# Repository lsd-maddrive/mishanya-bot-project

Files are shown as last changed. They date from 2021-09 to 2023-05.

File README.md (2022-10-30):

# mishanya-bot-project

Проект по разработке/оживлению человекоподного робота Мишаня -> [Описание робота](docs/equipment/equipment.md)

- [Подготовка окружения](#подготовка-окружения)
  - [Установка форматера глобально](#установка-форматера-глобально)
  - [Установка инструментов линта через локальное окружение (poetry)](#установка-инструментов-линта-через-локальное-окружение-poetry)
- [Пара моментов по разработке](#пара-моментов-по-разработке)
- [Заметки по работе в-целом](#заметки-по-работе-в-целом)
- [Глобальные цели](#глобальные-цели)
- [Ресурсы](#ресурсы)

## Подготовка окружения

Проект настроен на проверку кода по линтеру через GitHub actions. В результате проверки можно увидеть на [этой странице](https://github.com/lsd-maddrive/mishanya-bot-project/actions/workflows/lint.yml) в ветках. Можно брать проверки оттуда, а можно установить инструменты себе локально и проверять при каждой коммите (инструмент pre-commit) линтерами.

Для локальной работы линтеров нужно установить инструменты:

- pre-commit (python пакет)
- cpplint (python пакет)
- clang-format (бинарная утилита)

### Установка форматера глобально

Устанавливаем `clang-format`

- Windows

  Используйте установочный файл с [официального сайта LLVM](https://llvm.org/builds/) 

- Linux

  ```bash
  sudo apt install clang-format
  ```

### Установка инструментов линта через локальное окружение (poetry)

**Poetry** - это удобный инструмент для организации виртуального окружения.

1. Устанавливаем make
    - Windows:
  
      Устанавливаем [chocolatey](https://chocolatey.org/install) и устанавливаем `make` с помощью команды:

      ```bash
      choco install make 
      ```

    - Linux:

      ```bash
      sudo apt-get install build-essential
      ```

1. Устанавливаем `python 3.8`

   - Windows

      Устанавливаем через [официальный установщик](https://www.python.org/downloads/)

   - Linux

      ```bash
      sudo apt install python3.8-dev
      ```

1. Устанавливаем [poetry](https://python-poetry.org/docs/#installing-with-the-official-installer)

    - Windows

      Используйте [официальные инструкции](https://python-poetry.org/docs/#installing-with-the-official-installer) или команду `powershell`

      ```bash
      (Invoke-WebRequest -Uri https://install.python-poetry.org -UseBasicParsing).Content | py -
      ```

    - Linux

      ```bash
      make poetry-install
      ```

1. Устанавливаем требуемые пакеты и инструменты с помощью команды

    ```bash
    make env-init
    ```

## Пара моментов по разработке

- Основная разработка ведется через ветку `develop`
- Flow работы над задачей
  - Для нее обязательно должна быть создана задача в issues, например `#8 Разработка кода для модуля локтя руки`
  - Во вкладке Projects переводите ее в `In progress` колонку
  - Создаете ветку с названием `8_hand_module_code_creation`
  - Работаете в этой ветке (комитить желательно делать по завершении какой-то части задачи и всегда в конце дня)
  - После завершения работы создаете Pull Request, в котором описываете, что сделано и назначаете ревьюверов (всех остальных в проекте)
  - Как только ревью пройдено и получено подтверждение - ветку сливает администратор (Леша)
- Канбан доска для проекта - вкладка Projects
- Файлы больше 100 KB храним в [Git LFS](https://git-lfs.github.com/)
- Для каждой разработанной подсистемы требуется написать маленький тест, который будет запускать простую программу, использующую разработанные функции и демонстрировать работоспособность

## Заметки по работе в-целом

- Не стесняемся задавать вопросы по *любой* теме насчет проекта - лучше, чтобы все понимали, в каком состоянии что сейчас находится, чем что-то скрывать
- Чат не для хранения - его может заваливать переписками и общением!
- Документы, полезные ссылки или другая полезная инфа - обязательно в `.md` файлы в репозитории хранить!
- Если файлом надо поделиться - кладем в репо и отсюда кидаем ссылку в чат (так гарантируется, что ничего не потеряется) 

## Глобальные цели

- Stage 1 - Восстановление базового функционала
  - Стараемся добиться того, чтобы все части робота работали и все могло управляться через единый МК
- Stage 2 - Добавляется интеграция с ROS и организуется математическая модель кинематики с имплементацией в роботе
- Stage 3 - Разработка SDK для робота (прослойка для верхнеуровневого управления)
- Stage 4 - Разработка сценариев для автономного движения и выполнения задач (демо продукта, сбор информации с людей, и т.д.)

## Ресурсы

- [Хранилище больших файлов](https://disk.yandex.ru/d/VdiUvhrjdGQnWQ) (за доступом обращайтесь к [@KaiL4eK](https://github.com/KaiL4eK))

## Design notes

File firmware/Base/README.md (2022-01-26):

### TARGET

The template runs on an STM32 Nucleo64-F767ZI board.

### Useful links
* [Reference manual (RM)](https://www.st.com/content/ccc/resource/technical/document/reference_manual/group0/96/8b/0d/ec/16/22/43/71/DM00224583/files/DM00224583.pdf/jcr:content/translations/e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)
* [Datasheet (DS)](https://www.st.com/content/ccc/resource/technical/document/datasheet/group3/c5/37/9c/1d/a6/09/4e/1a/DM00273119/files/DM00273119.pdf/jcr:content/translations/en.DM002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)
* [Nucleo pinout](https://os.mbed.com/platforms/ST-Nucleo-F767zi/)

### Notes

Based on demos from https://github.com/ChibiOS/ChibiOS

### Information for developers

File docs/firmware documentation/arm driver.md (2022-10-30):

# arm driver v1.0 

Данный файл содержить информацию по использованию модуля `arm_driver`.
На данный момент с помощью данного модуля полностью описана работа:
- локтевого сустава робота `elbow_driver`;

## Описание конструкий

В h-файле находятся компоненты, которые описывают часть руки робота:

1. arm_side_t

enum для выбора левой или правой руки.

2. driver_t

enum для выбора типа драйвера:
- BB - управление осуществляется четырьмя выводами (4 ШИМ);
- RED - управление осуществляется тремя выводами (1 ШИМ, 2 дискретных).

3. pwm_channel_t

Структура с информацией о ШИМ-каналах

- uint8_t ch_pwm_1 - первый используемый канал ШИМ; 
- uint8_t ch_pwm_2 - второй используемый канал ШИМ;
- uint8_t alt_func_1 - номер альтернативной функции первого канала ШИМ;
- uint8_t alt_func_2 - номер альтернативной функции второго канала ШИМ.

4. pwm_ctx_t

Структура с информацией о настройках ШИМ.

- PWMDriver driver_ptr -  указатель на используемый таймер;
- PWMConfig pwm_conf -  структура с настройкой ШИМа;
- pwm_channel_t pwm_ch - описана в 4 пункте.

5. line_driver_t

Структура с информацией о используемых выводах.

- ioline_t     lin_1:
  * Нижний ключ первого полумоста при работе с BB;
  * Первый цифровой вывод при работе с RED.
- ioline_t     lin_2:
  * Нижний ключ второго полумоста при работе с BB;
  * Второй цифровой вывод при работе с RED.
- ioline_t     hin_1:
  * Верхний ключ первого полумоста при работе с BB;
  * Вывод ШИМ при работе с RED.
- ioline_t     hin_2:
  * Верхний ключ второго полумоста при работе с BB;
  * Не используется при работе с RED.

6. normalize_angle_t

- target - флаг был ли достигнут заданный угол
- target_angle - заданный угол;
- max_norm_angle - нормированное значение энкодера соответствущее максимальному углу;  
- min_norm_angle - нормированное значение энкодера соответствущее минимальному углу;
- shift - смещение между нулем и минимальным ненормированным углом;
- zero_cross - флаг есть ли нуль между крайними положениями энкодера.

7. angle_lim_t

- min_angle - минимальное положение энкодера 
- max_angle - максимальное положение энкодера

8. traking_cs_t

- normalize_angle - структура из пунтка 6;
- angle_lim - структура из пункта 7;
- arm_PID - настройка регулятора;
- angle_dead_zone - мертвая зона регулирования

9. control_driver_t

Объединяет в себе структуры из пункта 4 и 5.

10. arm_system_t

Объединяет в себе структуры из пункта 8 и 9.

11. arm_driver_ctx_t

Содержит enum из пункта 2, указатели на функции управления рукой
и массив из двух элементов типа control_driver_t (первый элемент описывает левую руку, второй правую). 

## Описание функций

Модуль содержит 4 функции:

1. Инициализация драйвера 
```c
void driver_init(const arm_driver_ctx_t *arm_driver);
```
Принимает полностью описанную часть руки робота.

2. Поднятие части руки робота вверх
```c
void arm_up(arm_side_t side, const arm_driver_ctx_t *arm_driver, uint16_t period);
```
Принимает выбор правой или левой руки, полностью описанную часть руки робота и необходимый период ШИМ.

3. Опускание части руки робота вверх
```c
void arm_down(arm_side_t side, const arm_driver_ctx_t *arm_driver, uint16_t period);
```
Принимает выбор правой или левой руки, полностью описанную часть руки робота и необходимый период ШИМ.

4. Выключение руки
```c
void arm_off (arm_side_t side, const arm_driver_ctx_t *arm_driver);
```
Принимает выбор правой или левой руки, полностью описанную часть руки робота и необходимый период ШИМ.

## Пример использования

В качестве примера рассмотрим применение модуля для описания локтевого сустава для BB-драйвера. 
Описание приведено для левой руки.

На момент написания, в локетвом суставе применялся 1 таймер STM32F411.

Для начала определим номера каналов, а также номер альтернативной функции. Используем 1 и 2 канал таймера. 
Номер альтернативной функции для 1 таймера в данном случае равен единице.

```c
const pwm_channel_t ch_left_pwm = {
    .ch_pwm_1 = 0,
    .ch_pwm_2 = 1,
    .alt_func_1 = 1,
    .alt_func_2 = 1
};
```

Определим структуру с настройками ШИМ:
```c
const pwm_ctx_t left_pwm_ctx = {
    .pwm_ch = ch_left_pwm,
    .driver_ptr = &PWMD1,
    .pwm_conf = {
    .frequency = PWM_frequency,
    .period    = PWM_period,
    .callback  = NULL,
    .channels  = {
            
            {.mode = PWM_OUTPUT_ACTIVE_HIGH | PWM_COMPLEMENTARY_OUTPUT_ACTIVE_HIGH, .callback = NULL},    // LEFT LIN1 & HIN1
            
            {.mode = PWM_OUTPUT_ACTIVE_HIGH | PWM_COMPLEMENTARY_OUTPUT_ACTIVE_HIGH, .callback = NULL},  // LEFT HIN2 & LIN2
            
            {.mode = PWM_OUTPUT_ACTIVE_HIGH | PWM_COMPLEMENTARY_OUTPUT_ACTIVE_HIGH, .callback = NULL},    // RIGHT LIN1 & HIN1
            
            {.mode = PWM_OUTPUT_ACTIVE_HIGH | PWM_COMPLEMENTARY_OUTPUT_ACTIVE_HIGH, .callback = NULL},  // RIGHT LN2 & HIN2I
        
        },
        .cr2        = 0,
        // !!!!!!!! THE CALCULATION WAS MADE FOR F411 !!!!!!!! //
        .bdtr         = 0b11111111,
        // !!!!!!!! THE CALCULATION WAS MADE FOR F411 !!!!!!!! //
        .dier       = 0
    }
};

```

Далее определяем выводы управления и формируем описание для левого локтевого сустава:
```c
const line_driver_t left_control = {
    .hin_1 = LEFT_HIN_1,
    .hin_2 = LEFT_HIN_2,
    .lin_1 = LEFT_LIN_1,
    .lin_2 = LEFT_LIN_2
};

const control_driver_t left_arm = {
    .line_control = left_control,
    .pwm_setting_ctx = left_pwm_ctx
};
```

Объявляем, но не инициализируем структуры контура управления и руки, далее они сведутся в elbow_driver:

traking_cs_t left_cs;
arm_system_t left_system;

arm_driver_ctx_t elbow_driver;

Аналогичным образом формируется описание для правого локтевого сустава, в функции init определяем структуры выше:

```c
left_cs.angle_lim = left_angle_lim;
left_cs.angle_dead_zone = ENCODER_DEADZONE;
left_cs.arm_PID = elbow_PID;

left_system.traking_cs = left_cs;
left_system.control = left_arm;

elbow_driver.type = DRIVER;
elbow_driver.down = &elbow_down;
elbow_driver.up = &elbow_up;
elbow_driver.off = &elbow_off;
elbow_driver.arm[0] = left_system;
elbow_driver.arm[1] = right_system;
```

Полученное описание можно использовать для вызова функций из arm_driver, получая более верхнеуровневые
их реализациия. Например, функция поднятия локтевого сустава просто вызывает arm_up, но при этом, чтобы
ее вызвать нам не надо вспоминать, какая именно структура описывает ту или иную часть робота. 
Мы просто выбирает соответствующую функцию и необходимую руку.

```c
void elbow_up(arm_side_t side, uint16_t period)
{
  arm_up(side, &elbow_driver, period);
}
```

## Допольнительная информация

Автор не утверждает, что данная реализация идеальна) Поэтому при наличии идей по доработке welcome.

По всем вопросам обращаться к [adhelll](https://github.com/adhelll).

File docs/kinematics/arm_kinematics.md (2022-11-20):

<p align="center">
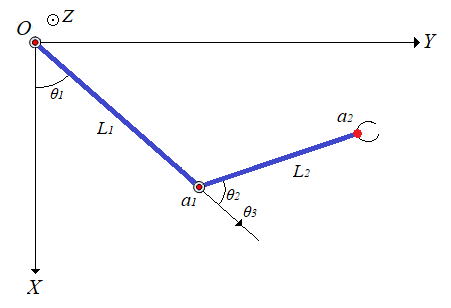
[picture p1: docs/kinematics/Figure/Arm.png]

</p>
<details>
<summary>Обозначения и значения параметров</summary>

Значение параметров взяты [отсюда](https://github.com/lsd-maddrive/mishanya-bot-project/blob/develop/docs/kinematics/dimensions.md)

| Обозначение | Смысл | Значение, ед. изм. |
|---|:---:|---:|
| *X,Y,Z / x,y,z* | абсолютные координаты | м |
| *X',Y',Z' / x',y',z',X'',Y'',Z'' / x'',y'',z''* | преобразованные координаты | м |
| , ,  | углы поворота звеньев манипулятора | рад |
| *L1* | Длина первого звена | 0.258 м |
| *L2* | Длина второго звена | 0.236 м |
| Пределы  | Изменение угла в системе координат | от -17 до 45 градусов |
| Пределы  | Изменение угла в системе координат |  от 46 до 86 градусов |
| Пределы  | Изменение угла в системе координат |  от -5 до 47 градусов |
</details>

Прямая кинематика:



Обратная кинематика:

Для начала введём несколько обозначений:
,  ,  ,  , где  - координаты желаемой точки.
Далее обозначим:
###


###



###

 или 

Окончательно:

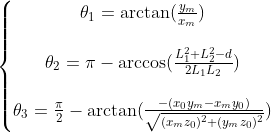
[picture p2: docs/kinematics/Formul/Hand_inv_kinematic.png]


###
<details>
<summary>Вывод уравнений</summary>

Для прямой кинематики:

Для начала отметим, что точки a1 и a2 всегда лежат в одной плоскости, которую мы будем называть плоскостью манипулятора. Внутри этой плоскости они однозначно связаны через угол , поэтому сразу вычислим эту связь.

Первое звено L1 закреплёно одним концом на плече в точки О и поворачивается на угол ,
второе звено L2 крепится к концу первого звена в точке a1 и поворачивается относительно него на угол .
Задавать мы пытаемся координаты конца второго звена - точки a2.

Найдём сначала положение точки a1 относительно точки крепления плеча:



Далее положение точки a2 относительно точки a1:



Так как система координат, привязанная к точке a1 также вращается - учтём это в относитльном положении для точки a2. Расчёт коордиеат во вращающейся системе осуществляется с использованием матрицы поворота: умножаем предыдущую систему на матрицу поворота угла . Таким образом положение точки a2 относительно точки a1 в случае вращающейся системы координат получим:



Раскрыв правую часть и используя формулу косинуса и синуса суммы углов, получим:



Если помимо вращение системы координат, привязанной к точки a1, учесть также смещение этой точки относительно начала глобальной системы координат, которое по сути равно координатам точки a1 в этой глобальной системе, окончательно получим:



Далее заметим, что остальные углы лишь поворачивают эту плоскость вокруг какой-то произвольной оси. Для задания этих поворотов воспользуемся углами Эйлера. Они позволяют сложное вращательное движение в пространстве(у нас нет поступательных движений) представить как последовательное вращение вокруг определённых осей, что более простая задача. Все формулы были взяты [отсюда](https://ru.wikipedia.org/wiki/%D0%A3%D0%B3%D0%BB%D1%8B_%D0%AD%D0%B9%D0%BB%D0%B5%D1%80%D0%B0). Пускай начальное положение манипулятора лежит полностью в плоскости XY, причём так, что ось звена L1 сонаправлена с осью X, т.е. следующим образом:

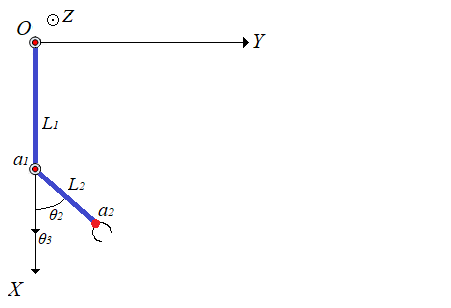
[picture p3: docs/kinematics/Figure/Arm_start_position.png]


Сделали мы так, чтобы вращение вокруг звена L1 совпадало с вращением вокруг оси X, а не было вращением вокруг какой-то произвольно ориентированной в пространстве оси. Таким образом, сделав вращение сначала вокруг оси X на угол  из начального положения, а после из нового положения - вокруг оси Z на угол , мы получим полный поворот манипулятора с учётом всех углов. Формулы вращения вокруг осей системы координат известные и просты(ссылка выше), и представление сложного пространственного движения через последовательные более простые преобразования позволяет упростить задачу.

С учётом вышевыведенных формул, в начальном положении у нас  = 0, а  произвольный, получим:



Далее мы нашу систему координат, как уже было сказано, поворачиваем вокруг оси X на угол . Тогда с учётом вида матрицы вращения вокруг оси X наше преобразование будет иметь вид:



Получим:



После поворачиваем вокруг оси Z на угол . Тогда с учётом вида матрицы вращения вокруг оси Z наше преобразование будет иметь вид:



После перемножения получим формулу прямой кинематики, которая приведена в начале.

В силу громоздкости записи и вычислений был использован матлаб-скрипт [Hand_formul.m](Script/Hand_formul.m). Cкрипт выводит все символьные выражения.

Для обратной кинематики:

Для начала упростим задачу. Представим, что звено L1 может двигаться не только в плоскости но и вообще во всём пространстве(относительно точки плеча), тогда все возможные положения конца звена - точки локтя будут описывать сферу с радиусом L1 и центром в точке плеча(в центре системы координат). Далее, мы знаем, что точка хвата должна оказаться в желаемой точке, чьи координаты заданы, при этом точку хвата описывает координаты конца звена L2, которые в свою очередь определяются координатами локтя. Представим, что точка хвата достигла желаемой точки, тогда всё возможные положения точки локтя лежат на сфере радиуса L2 и с центром - желаемой точкой(мысленно поставим точку хвата в желамую точку и покрутим предплечьем(звеном L2) во все стороны). Таким образом положения точки локтя при осуществелении обеих условий(1. начало звена L1 зафиксировано в начале координат, 2. точка хвата лежит в желаемой точке, а точка локтя жёстко связана с ней через звено L2) будет лежать на перечении этих двух сфер. Найдём координаты этих точек, для этого нужно решить систему:



где первое уравнение описывает первую сферу, второе - вторую.  - координаты желаемой точки.

Раскроем во втором уравнении скобки:



Вместо суммы квадратов координат можно поставить первое уравнение. Сумму квадратов координат желаемой точки обозначим за d. С учтом подстановок и обозначение перенесём всё влево:



Обозначим  за D. В итоге получим уравнение плоскости вида:

,

где  ,  ,  соответственно.

Вообще пересечением сфер является окружность, но так как сложно описать уравнение окружности, произвольно лежащей в пространстве, мы получили уравнение плоскости, в которой лежит нужная нам окружность. Так как из всей плоксоти нам нужны конкретные точки, а именно лежащие на сфере, мы должны совместно решить уравнение плоскости и уравнение какой-нибудь из сфер(возьмём первое для удобства)(кстати, система из уравнения плоскости и сферы как раз даёт уравнение окружности произвольно ориентированной в пространстве), также вспомним, что мы опустили условие, что звено L1 может двигаться только в плоскости, поэтому сразу добавим третьим уравнением - уравнение плоскости L1, так как этой плоскостью является XY, то её уравнением будет просто z = 0. В итоге получим:



Можем сразу подставить z=0 в два другим уравнения и получим:



Из второго уравнения выразим x:



и подставим это в первое уравнение:





###



###



###



Отсюда можно найти решение - координату локтя:



А по формулам полученным выше можно найти вторую координату:



или если нужно избежать возможное деление на ноль



Зная координаты локтя, можно найти угол поворота первого звена, как:



Для нахождения угла  вспоним сначала, что это поворот плоскости манипулятора вокруг первого звена, значит нахождения этого угла можно поставить как задачу расчёта угла между плоскостями: исходной(XY) и новой(желаемой), которые имеют общую прямую пересечения(которая проходит через первое звено). Плоскость можно задавать с помощью координат нормали к этой плоскости. Для исходной плоскости это будет единичный вектор сонаправленный с осью Z. Для получения уравнения координат нормали к новой плоскости, построим сначала уравнение самой плоскости. Для этого используем уравнение:



где вертикальные черты означают определитель,  - координаты трёх точек, по которым строится плоскость. В качестве трёх точек возьмём начало координат, координаты локтя, желаемую точку, в итоге получим уравнение желамеой плоскости манипулятора:



коэффициенты при переменных - и будут координатами нормали к данной плоскости. Тогда мы можем воспользоваться формулой косинуса угла между пересекающимеся плоскостями по координатам их нормали:



так как нам важен знак(четверть угла), то воспользуемся формулой:



Подставляя координаты наших нормалей получим:



Из-за громоздкости выражений и расчётов был использован скрипт для символьных выражений [Ang_plosk.m](Script/Ang_plosk.m), который выводит выражения выше. От арккосинуса перейдём к арктангенсу, так как он позволяет сократить выражение, а также имеет специлизированные функции, защищающие от случай деления на ноль. Для этого сделаем преобразование:



Используем выражение:



Для этого сделаем преобразование:





минус в одной из скобок знаменателя был добавлен так как дробь стоит под квадратом, а в знаменателе корень, который не меняет знака

С учётом всех вышеперечисленных выражений, получим:



или



Для нахождения угла  достаточно знать, что он всегда лежит в плоскости манипулятора, а значит для его нахождения можно рассмотреть манипулятор как плоскую фигуру. Построим:

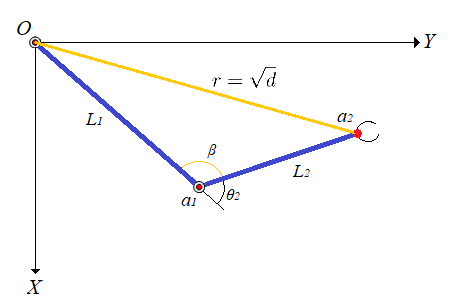
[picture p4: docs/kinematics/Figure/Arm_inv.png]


нужный нам угол составляет с углом  180 градусов. Угол  мы можем найти из теоремы косинусов:



###


Тогда с заменой  на  получим:



</details>

###
Для проверки работоспособности можно воспользоваться скриптом [Proverka.m](Script/Proverka.m)

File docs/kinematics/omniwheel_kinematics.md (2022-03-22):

<p align="center">
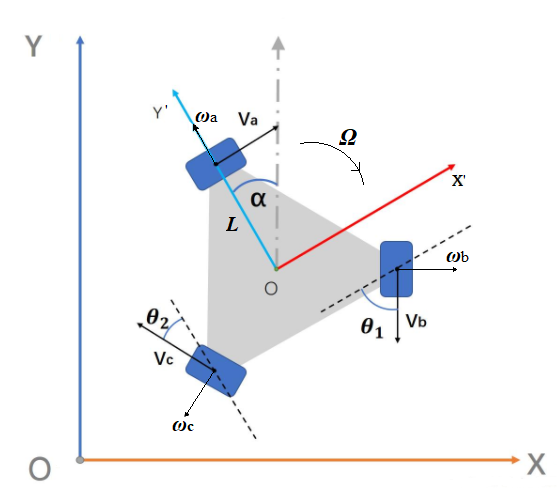
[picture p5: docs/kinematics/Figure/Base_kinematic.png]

</p>
<details>
<summary>Обозначения и значения параметров</summary>

Значение параметров взяты [отсюда](https://github.com/lsd-maddrive/mishanya-bot-project/blob/develop/docs/kinematics/dimensions.md)

| Обозначение| Смысл| Значение, ед. изм.|
| ---|:---:| ---:|
| *XY* | абсолютная система координат | м |
| *X'Y'* | связанная система координат | м |
|  | угол поворота основания | рад |
|  | угловая скорость основания | рад/с |
| *L* | радиус основания | 0.40643 м |
|  | линейные скорости основания в абсолютной системе | м/с |
||линейные скорости омниколёс|м/с|
||угловые скорости омниколёс|рад/с|
|*r*|радиус омниколёс|0.061 м|

</details>

###
Прямая кинематика:



Обратная кинематика:


###
<details>
<summary>Вывод уравнений</summary>
Для вывода уравнений прямой кинематики сначала найдём преобразование из абсолютной системы координат(XY) в систему координат, связанную с платформой(X'Y'). Преобразование это из себя представляет поворот системы координат на угол поворота самой платформы - . Исходную систему и повёрнутую связывает простая матрицы поворота:

######


Такая же матрица поворота будет связывать проекции скоростей в своих системах координат:



Для уравнений прямой кинематики нам нужно связать скорости платформы с угловыми скоростями омниколёс. Так как рассматриваем мы линейные скорости, то нужно сначала получить линейные скорости, с которым колесо будет "катиться" при заданной угловой. Путь, пройденный колесом, равен длине дуги, которая опирается на угол, на который повернулось колесо, в силу их "соприкосновения" (в отсутствии скольжения). Длина дуги связана с углом поворота через радиус колеса, поэтому и линейная с угловой скорости тоже будут связаны через радиус:



Данное выражение для угловой скорости, выраженной в рад/с. Чтобы использовать скорость, выраженной в  нужно домножить правую часть на . Теперь зная это мы можем спокойной работать пока с линейными скоростями, так как они линейно связаны с угловыми.

Теперь выразим линейные скорости платформы через проекции скоростей колёс на оси связанной системы координат. Пусть линейная скорость одного из колёс всегда соноправлена с одной из осей(в нашем случае - скорость колеса `a` с осью X'). Тогда вектор скорости колеса `b` будет отстоять от оси X'(если точнос - от -X') на угол (или ), что не сложно рассчитать, если учитывать, что угол между осями колёс = . Значит проекции скорости колеса `b` по осям будут соответственно:





Вектор скорости колеса `с` будет отстоять от оси Y'(от -Y') на угол (или ). Его проекции по осям будут соответсвенно:





Чтобы получить результирующую скорость по каждой из осей - просто сложим проекции по соответсвующим осям:





Данные уравнения можно представить в матричной форме:



Теперь нам нужно вернуться в исходную систему координат. Так как у нас тут по сути последовательное применение линейных преобразований, мы можем просто перемножить матрицы в нужном порядке:




Видно, что некоторые компоненты полученной матрицы представляют из себя по сути формулы косинуса/синуса суммы/разницы. Упростив эти компоненты по соответствующим правилам получим в итоге:



То есть связь для линейных скоростей:



Для полного набора переменных, характеризующих движение платформы нам также нужна её угловая скорость. Для её расчёта на не нужны геометрические преобразования, так как она явно зависит от скоростей колёс. По аналогии с рассуждениями о линейной и угловой скорости колеса, угловая скорость платформы равна линейной скорости на расстоянии радиуса умноженной на этот радиус. Скоростей у нас три, поэтому угловая скорость будет равна сумме составляющих по каждой из них:



Это уравнение мы спокойно можем добавить в общую систему, так как она линейно зависит от скоростей:



Чтобы система всё же была выражена через угловые скорости колёс, вынесем радиус колеса из вектора линейных скоростей(радиус всех колёс предпологается одинаковым):



Теперь достаточно подставить чиленные значения углов и получить нашу систему.

Для расчёта обратной кинематики можно проделать похожие рассуждения но "в обратную сторону". Но проще поступить иначе. Так как прямая кинематика - это по сути линейное преобразование, то чтобы получить обратную - нужно в уравнениях прямой кинематики домножить правую и левую части на обратную матрицу преобразования. Но так как у нас по сути преобразование только вращения и нет смещения(нет явно выраженного слагаемого и матрица не соответствует форме однородного преобразования), то обратная матрица будет равна транспонированной матрице. Единственное что к масштабирующему коэффициенту нужно будет взять обратное значение, так как преобразование вращение и обратное к ней взаимны без маштабирования. Отсюда получаем:



Окончательно:



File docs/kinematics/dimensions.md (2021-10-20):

##  Размеры ##
Размеры указываются в сантиметрах
1. Рука
    - Длина плеча = 25.8
    - Длина коробки линейного двигателя = 15.5
    - Длина предплечья до сочленения с кистью = 23.6
    - Длина кисти без учёта клишни = 5.5
    - Длина вала линейного двигателя(от конца до коробки):
        - В верхнем положении = 7.45
        - В нижнем = 1.5
    - Расстояние от конца вала линейного двигателя до сустава руки = 3.7
    - Расстояние от конца линейного двигателя до сустава плеча, вращение вокруг которого идёт параллельно корпусу = 4.25
    - Расстояние от конца линейного двигателя до сустава плеча, вращение вокруг которого идёт перпендикулярно корпусу = 4.5
2. Основание
    - радиус основания = 40.643
    - высота основания = 21
    - ширина колеса(два ряда) = 6.3
    - радиус колеса = 6.1
3. Корпус
    - расстояние между плечами = 60.4
    - высота корпуса(без основания) = 110.2

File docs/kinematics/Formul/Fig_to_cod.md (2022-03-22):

Для омниколёс:

 - <a href="https://www.codecogs.com/eqnedit.php?latex=\alpha" target="_blank">\alpha</a>
 - <a href="https://www.codecogs.com/eqnedit.php?latex=\Omega" target="_blank">\Omega</a>
 - <a href="https://www.codecogs.com/eqnedit.php?latex=V_{x},V_{y}" target="_blank">V_{x},V_{y}</a>
 - <a href="https://www.codecogs.com/eqnedit.php?latex=V_{a},V_{b},V_{c}" target="_blank">V_{a},V_{b},V_{c}</a>
 - <a href="https://www.codecogs.com/eqnedit.php?latex=\omega_{a},\omega_{b},\omega_{c}" target="_blank">\omega_{a},\omega_{b},\omega_{c}</a>

 - <a href="https://www.codecogs.com/eqnedit.php?latex=\begin{bmatrix}V_{x}\\V_{y}&space;\\&space;\Omega\end{bmatrix}&space;=r&space;\begin{bmatrix}cos(&space;\alpha&space;)&-cos(&space;\alpha&plus;&space;\frac{&space;\pi&space;}{3}&space;)&-sin(&space;\alpha&plus;&space;\frac{&space;\pi&space;}{6})&space;\\sin(&space;\alpha)&space;&-sin(&space;\alpha&plus;&space;\frac{&space;\pi&space;}{3}&space;)&cos(&space;\alpha&plus;&space;\frac{&space;\pi&space;}{6}&space;)\\L&L&L\end{bmatrix}&space;\begin{bmatrix}\omega_{a}\\\omega_{b}&space;\\&space;\omega_{c}\end{bmatrix}" target="_blank">\begin{bmatrix}V_{x}\\V_{y} \\ \Omega\end{bmatrix} =r \begin{bmatrix}cos( \alpha )&-cos( \alpha+ \frac{ \pi }{3} )&-sin( \alpha+ \frac{ \pi }{6}) \\sin( \alpha) &-sin( \alpha+ \frac{ \pi }{3} )&cos( \alpha+ \frac{ \pi }{6} )\\L&L&L\end{bmatrix} \begin{bmatrix}\omega_{a}\\\omega_{b} \\ \omega_{c}\en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</a>

 - <a href="https://www.codecogs.com/eqnedit.php?latex=\begin{bmatrix}\omega_{a}\\\omega_{b}&space;\\&space;\omega_{c}\end{bmatrix}&space;=&space;\frac{1}{r}&space;\begin{bmatrix}cos(&space;\alpha&space;)&sin(&space;\alpha&space;)&L&space;\\&space;-cos(&space;\alpha&plus;&space;\frac{&space;\pi&space;}{3}&space;)&-sin(&space;\alpha&plus;&space;\frac{&space;\pi&space;}{3}&space;)&L&space;\\&space;-sin(&space;\alpha&plus;&space;\frac{&space;\pi&space;}{6}&space;)&cos(&space;\alpha&plus;&space;\frac{&space;\pi&space;}{6}&space;)&L&space;\end{bmatrix}&space;\begin{bmatrix}V_{x}\\V_{y}&space;\\&space;\Omega\end{bmatrix}" target="_blank">\begin{bmatrix}\omega_{a}\\\omega_{b} \\ \omega_{c}\end{bmatrix} = \frac{1}{r} \begin{bmatrix}cos( \alpha )&sin( \alpha )&L \\ -cos( \alpha+ \frac{ \pi }{3} )&-sin( \alpha+ \frac{ \pi }{3} )&L \\ -sin( \alpha+ \frac{ \pi }{6} )&cos( \alpha+ \frac{ \pi }{6} )&L \end{bmatrix} \begin{bmatrix}V_{x}\\V_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</a>

 - <a href="https://www.codecogs.com/eqnedit.php?latex=\begin{bmatrix}X\\Y\end{bmatrix}&space;=&space;\begin{bmatrix}cos(&space;\alpha&space;)&-sin(&space;\alpha&space;)\\&space;sin(&space;\alpha)&cos(&space;\alpha&space;)\end{bmatrix}&space;\begin{bmatrix}X'\\Y'\end{bmatrix}" target="_blank">\begin{bmatrix}X\\Y\end{bmatrix} = \begin{bmatrix}cos( \alpha )&-sin( \alpha )\\ sin( \alpha)&cos( \alpha )\end{bmatrix} \begin{bmatrix}X'\\Y'\end{bmatrix}</a>

 - <a href="https://www.codecogs.com/eqnedit.php?latex=\begin{bmatrix}V_{x}\\V_{y}\end{bmatrix}&space;=&space;\begin{bmatrix}cos(&space;\alpha&space;)&-sin(&space;\alpha&space;)\\&space;sin(&space;\alpha)&cos(&space;\alpha&space;)\end{bmatrix}&space;\begin{bmatrix}V_{x'}\\V_{y'}\end{bmatrix}" target="_blank">\begin{bmatrix}V_{x}\\V_{y}\end{bmatrix} = \begin{bmatrix}cos( \alpha )&-sin( \alpha )\\ sin( \alpha)&cos( \alpha )\end{bmatrix} \begin{bmatrix}V_{x'}\\V_{y'}\end{bmatrix}</a>

 - <a href="https://www.codecogs.com/eqnedit.php?latex=v=r\cdot\omega" target="_blank">v=r\cdot\omega</a>

 - <a href="https://www.codecogs.com/eqnedit.php?latex={^\circ}/c" target="_blank">{^\circ}/c</a>

 - <a href="https://www.codecogs.com/eqnedit.php?latex=\frac{&space;\pi}{&space;{180^\circ}}" target="_blank">\frac{ \pi}{ {180^\circ}}</a>

 - <a href="https://www.codecogs.com/eqnedit.php?latex=\theta&space;_{1}=&space;60^\circ" target="_blank">\theta _{1}= 60^\circ</a>

 - <a href="https://www.codecogs.com/eqnedit.php?latex=\pi/3" target="_blank">\pi/3</a>

 - <a href="https://www.codecogs.com/eqnedit.php?latex=120^\circ" target="_blank">120^\circ</a>

 - <a href="https://www.codecogs.com/eqnedit.php?latex=X':-V_{b}\cdot&space;\cos(&space;\theta&space;_{1})" target="_blank">X':-V_{b}\cdot \cos( \theta _{1})</a>

 - <a href="https://www.codecogs.com/eqnedit.php?latex=Y':-V_{b}\cdot&space;\sin(&space;\theta&space;_{1})" target="_blank">Y':-V_{b}\cdot \sin( \theta _{1})</a>

 - <a href="https://www.codecogs.com/eqnedit.php?latex=\theta&space;_{2}&space;=&space;30^\circ" target="_blank">\theta _{2} = 30^\circ</a>

 - <a href="https://www.codecogs.com/eqnedit.php?latex=\pi/6" target="_blank">\pi/6</a>

 - <a href="https://www.codecogs.com/eqnedit.php?latex=X':-V_{c}\cdot&space;\sin(&space;\theta&space;_{2})" target="_blank">X':-V_{c}\cdot \sin( \theta _{2})</a>

 - <a href="https://www.codecogs.com/eqnedit.php?latex=Y':V_{c}\cdot&space;\cos(&space;\theta&space;_{2})" target="_blank">Y':V_{c}\cdot \cos( \theta _{2})</a>

 - <a href="https://www.codecogs.com/eqnedit.php?latex=V_{x'}=V_{a}-V_{b}\cdot&space;\cos(&space;\theta&space;_{1})-V_{c}\cdot&space;\sin(&space;\theta&space;_{2})" target="_blank">V_{x'}=V_{a}-V_{b}\cdot \cos( \theta _{1})-V_{c}\cdot \sin( \theta _{2})</a>

 - <a href="https://www.codecogs.com/eqnedit.php?latex=V_{y'}=-V_{b}\cdot&space;\sin(&space;\theta&space;_{1})&plus;V_{c}\cdot&space;\cos(&space;\theta&space;_{2})" target="_blank">V_{y'}=-V_{b}\cdot \sin( \theta _{1})+V_{c}\cdot \cos( \theta _{2})</a>

 - <a href="https://www.codecogs.com/eqnedit.php?latex=\begin{bmatrix}V_{x'}\\V_{y'}\end{bmatrix}&space;=&space;\begin{bmatrix}1&&space;-\cos(&space;\theta_{1})&-\sin(&space;\theta_{2})\\&space;0&-\sin(&space;\theta_{1})&space;&\cos(&space;\theta_{2})\end{bmatrix}&space;\begin{bmatrix}V_{a}\\V_{b}&space;\\&space;V_{c}\end{bmatrix}" target="_blank">\begin{bmatrix}V_{x'}\\V_{y'}\end{bmatrix} = \begin{bmatrix}1& -\cos( \theta_{1})&-\sin( \theta_{2})\\ 0&-\sin( \theta_{1}) &\cos( \theta_{2})\end{bmatrix} \begin{bmatrix}V_{a}\\V_{b} \\ V_{c}\end{bmatrix}</a>

 - <a href="https://www.codecogs.com/eqnedit.php?latex=\begin{bmatrix}\cos(&space;\alpha)&-\sin(&space;\alpha)\\&space;\sin(&space;\alpha)&\cos(&space;\alpha)\end{bmatrix}&space;\begin{bmatrix}1&&space;-\cos(&space;\theta_{1})&-\sin(&space;\theta_{2})\\&space;0&-\sin(&space;\theta_{1})&space;&\cos(&space;\theta_{2})\end{bmatrix}=" target="_blank">\begin{bmatrix}\cos( \alpha)&-\sin( \alpha)\\ \sin( \alpha)&\cos( \alpha)\end{bmatrix} \begin{bmatrix}1& -\cos( \theta_{1})&-\sin( \theta_{2})\\ 0&-\sin( \theta_{1}) &\cos( \theta_{2})\end{bmatrix}=</a>

 - <a href="https://www.codecogs.com/eqnedit.php?latex=\begin{bmatrix}\cos(&space;\alpha)&&space;\sin(&space;\theta_{1})\sin(&space;\alpha)-\cos(&space;\theta_{1})\cos(&space;\alpha)&-\cos(&space;\theta_{2})\sin(&space;\alpha)-\sin(&space;\theta_{2})\cos(&space;\alpha)\\\sin(&space;\alpha)&-\cos(&space;\theta_{1})\sin(&space;\alpha)-\sin(&space;\theta_{1})\cos(&space;\alpha)&\cos(&space;\theta_{2})\cos(&space;\alpha)-\sin(&space;\theta_{2})\sin(&space;\alpha)\end{bmatrix}" target="_blank">\begin{bmatrix}\cos( \alpha)& \sin( \theta_{1})\sin( \alpha)-\cos( \theta_{1})\cos( \alpha)&-\cos( \theta_{2})\sin( \alpha)-\sin( \theta_{2})\cos( \alpha)\\\sin( \alpha)&-\cos( \theta_{1})\sin( \alpha)-\sin( \theta_{1})\cos( \alpha)&\cos( \theta_{2})\cos( \alpha)-\sin( \theta_{2})\sin( \alpha)\end{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</a>

 - <a href="https://www.codecogs.com/eqnedit.php?latex=\begin{bmatrix}\cos(&space;\alpha)&&space;-\cos(&space;\alpha&plus;&space;\theta&space;_{1})&&space;-\sin(&space;\alpha&plus;&space;\theta&space;_{2})\\\sin(&space;\alpha)&-\sin(&space;\alpha&plus;&space;\theta&space;_{1})&\cos(&space;\alpha&plus;&space;\theta&space;_{2})\end{bmatrix}" target="_blank">\begin{bmatrix}\cos( \alpha)& -\cos( \alpha+ \theta _{1})& -\sin( \alpha+ \theta _{2})\\\sin( \alpha)&-\sin( \alpha+ \theta _{1})&\cos( \alpha+ \theta _{2})\end{bmatrix}</a>

 - <a href="https://www.codecogs.com/eqnedit.php?latex=\begin{bmatrix}V_{x}\\V_{y}\end{bmatrix}=\begin{bmatrix}\cos(&space;\alpha)&&space;-\cos(&space;\alpha&plus;&space;\theta&space;_{1})&&space;-\sin(&space;\alpha&plus;&space;\theta&space;_{2})\\\sin(&space;\alpha)&-\sin(&space;\alpha&plus;&space;\theta&space;_{1})&\cos(&space;\alpha&plus;&space;\theta&space;_{2})&space;\end{bmatrix}\begin{bmatrix}V_{a}\\V_{b}\\V_{c}\end{bmatrix}" target="_blank">\begin{bmatrix}V_{x}\\V_{y}\end{bmatrix}=\begin{bmatrix}\cos( \alpha)& -\cos( \alpha+ \theta _{1})& -\sin( \alpha+ \theta _{2})\\\sin( \alpha)&-\sin( \alpha+ \theta _{1})&\cos( \alpha+ \theta _{2}) \end{bmatrix}\begin{bmatrix}V_{a}\\V_{b}\\V_{c}\end{bmatrix}</a>

 - <a href="https://www.codecogs.com/eqnedit.php?latex=\Omega&space;=&space;L\cdot&space;V_{a}&plus;L\cdot&space;V_{b}&plus;L\cdot&space;V_{c}" target="_blank">\Omega = L\cdot V_{a}+L\cdot V_{b}+L\cdot V_{c}</a>

 - <a href="https://www.codecogs.com/eqnedit.php?latex=\begin{bmatrix}V_{x}\\V_{y}\\\Omega\end{bmatrix}=\begin{bmatrix}\cos(&space;\alpha)&&space;-\cos(&space;\alpha&plus;&space;\theta&space;_{1})&&space;-\sin(&space;\alpha&plus;&space;\theta&space;_{2})\\\sin(&space;\alpha)&-\sin(&space;\alpha&plus;&space;\theta&space;_{1})&\cos(&space;\alpha&plus;&space;\theta&space;_{2})&space;\\L&L&L&space;\end{bmatrix}\begin{bmatrix}V_{a}\\V_{b}\\V_{c}\end{bmatrix}" target="_blank">\begin{bmatrix}V_{x}\\V_{y}\\\Omega\end{bmatrix}=\begin{bmatrix}\cos( \alpha)& -\cos( \alpha+ \theta _{1})& -\sin( \alpha+ \theta _{2})\\\sin( \alpha)&-\sin( \alpha+ \theta _{1})&\cos( \alpha+ \theta _{2}) \\L&L&L \end{bmatrix}\begin{bmatrix}V_{a}\\V_{b}\\V_{c}\end{bmatrix}</a>

 - <a href="https://www.codecogs.com/eqnedit.php?latex=\begin{bmatrix}V_{x}\\V_{y}\\\Omega\end{bmatrix}=r\begin{bmatrix}\cos(&space;\alpha)&&space;-\cos(&space;\alpha&plus;&space;\theta&space;_{1})&&space;-\sin(&space;\alpha&plus;&space;\theta&space;_{2})\\\sin(&space;\alpha)&-\sin(&space;\alpha&plus;&space;\theta&space;_{1})&\cos(&space;\alpha&plus;&space;\theta&space;_{2})&space;\\L&L&L&space;\end{bmatrix}\begin{bmatrix}\omega_{a}\\\omega_{b}\\\omega_{c}\end{bmatrix}" target="_blank">\begin{bmatrix}V_{x}\\V_{y}\\\Omega\end{bmatrix}=r\begin{bmatrix}\cos( \alpha)& -\cos( \alpha+ \theta _{1})& -\sin( \alpha+ \theta _{2})\\\sin( \alpha)&-\sin( \alpha+ \theta _{1})&\cos( \alpha+ \theta _{2}) \\L&L&L \end{bmatrix}\begin{bmatrix}\omega_{a}\\\omega_{b}\\\omega_{c}\end{bmatrix}</a>

 - <a href="https://www.codecogs.com/eqnedit.php?latex=\begin{bmatrix}\omega_{a}\\\omega_{b}\\\omega_{c}\end{bmatrix}=\frac{1}{r}\begin{bmatrix}\cos(&space;\alpha)&&space;-\cos(&space;\alpha&plus;&space;\theta&space;_{1})&&space;-\sin(&space;\alpha&plus;&space;\theta&space;_{2})\\\sin(&space;\alpha)&-\sin(&space;\alpha&plus;&space;\theta&space;_{1})&\cos(&space;\alpha&plus;&space;\theta&space;_{2})&space;\\L&L&L&space;\end{bmatrix}^{T}\begin{bmatrix}V_{x}\\V_{y}\\\Omega\end{bmatrix}" target="_blank">\begin{bmatrix}\omega_{a}\\\omega_{b}\\\omega_{c}\end{bmatrix}=\frac{1}{r}\begin{bmatrix}\cos( \alpha)& -\cos( \alpha+ \theta _{1})& -\sin( \alpha+ \theta _{2})\\\sin( \alpha)&-\sin( \alpha+ \theta _{1})&\cos( \alpha+ \theta _{2}) \\L&L&L \end{bmatrix}^{T}\begin{bmatrix}V_{x}\\V_{y}\\\Omega\end{bma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</a>

 - <a href="https://www.codecogs.com/eqnedit.php?latex=\begin{bmatrix}\omega_{a}\\\omega_{b}&space;\\&space;\omega_{c}\end{bmatrix}&space;=&space;\frac{1}{r}&space;\begin{bmatrix}\cos(&space;\alpha&space;)&\sin(&space;\alpha&space;)&L&space;\\&space;-\cos(&space;\alpha&plus;&space;\theta&space;_{1})&-\sin(&space;\alpha&plus;&space;\theta&space;_{1})&L&space;\\&space;-\sin(&space;\alpha&plus;&space;\theta&space;_{2})&\cos(&space;\alpha&plus;&space;\theta&space;_{2})&L&space;\end{bmatrix}&space;\begin{bmatrix}V_{x}\\V_{y}\\\Omega\end{bmatrix}" target="_blank">\begin{bmatrix}\omega_{a}\\\omega_{b} \\ \omega_{c}\end{bmatrix} = \frac{1}{r} \begin{bmatrix}\cos( \alpha )&\sin( \alpha )&L \\ -\cos( \alpha+ \theta _{1})&-\sin( \alpha+ \theta _{1})&L \\ -\sin( \alpha+ \theta _{2})&\cos( \alpha+ \theta _{2})&L \end{bmatrix} \begin{bmatrix}V_{x}\\V_{y}\\\Omega\en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</a>
</details>

Для руки:

 - https://latex.codecogs.com/svg.image?\begin{cases}x = \cos( \theta_{1})\cdot (L_{1}+L_{2}\cos( \theta _{2}))-L_{2}\cos( \theta _{3})\sin( \theta_{1})\sin( \theta_{2})\\y = \sin( \theta_{1})\cdot (L_{1}+L_{2}\cos( \theta _{2}))+L_{2}\cos( \theta _{1})\cos( \theta_{3})\sin( \theta_{2})\\z = L_{2}\sin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

 - http://latex.codecogs.com/svg.latex?A = -2\cdot x_{0}

 - http://latex.codecogs.com/svg.latex?B = -2\cdot y_{0}

 - http://latex.codecogs.com/svg.latex?C = -2\cdot z_{0}

 - http://latex.codecogs.com/svg.latex?d = x_{0}^{2} + y_{0}^{2} + z_{0}^{2}

 - http://latex.codecogs.com/svg.latex?x_{0}, y_{0}, z_{0}

 - http://latex.codecogs.com/svg.latex?D = L_{1}^{2} - L_{2}^{2} + d

 - http://latex.codecogs.com/svg.latex?y_{m_{1,2}} = \frac{-2DB\pm \sqrt{(2DB)^{2}-4(A^{2}+B^{2})(D^{2}-(AL_{1})^{2})}}{2(A^{2}+B^{2})}

 - http://latex.codecogs.com/svg.latex?x_{m_{1,2}} = \frac{-D-By_{m_{1,2}}}{A}

 - https://latex.codecogs.com/svg.image?x_{m_{1,2}} = \sqrt{L_{1}^{2}-y_{m_{1,2}}^{2}}

 - https://latex.codecogs.com/svg.image?\left\{\begin{matrix}\theta _{1}=\arctan(\frac{y_{m}}{x_{m}})\\\\\theta _{2}=\pi -\arccos(\frac{L_{1}^{2}+L_{2}^{2}-d}{2L_{1}L_{2}})\\\\\theta _{3}=\frac{\pi}{2} - \arctan(\frac{-(x_{0}y_{m}-x_{m}y_{0})}{\sqrt{(x_{m}z_{0})^{2}+(y_{m}z_{0})^{2}}})\end{matrix}\rig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

 - https://latex.codecogs.com/svg.image?\theta_{2}

 - \theta _{1}

 - \left\{\begin{matrix}X_{a1}=L_{1}\cdot \sin( \theta _{1})\\Y_{a1}=L_{1}\cdot \cos( \theta _{1})\end{matrix}\right.

 - \left\{\begin{matrix}X_{a2}^{'}=L_{2}\cdot \sin( \theta _{2})\\Y_{a2}^{'}=L_{2}\cdot \cos( \theta _{2})\end{matrix}\right.

 - \begin{bmatrix}X_{a2}^{''}\\Y_{a2}^{''}\end{bmatrix} = \begin{bmatrix}cos( \theta _{1} )&-sin( \theta _{1} )\\ sin( \theta _{1})&cos( \theta _{1} )\end{bmatrix} \begin{bmatrix}L_{2}\cdot \sin( \theta _{2})\\L_{2}\cdot \cos( \theta _{2})\end{bmatrix}

 - \left\{\begin{matrix}X_{a2}^{''}=L_{2}\cdot \cos( \theta _{1} + \theta _{2})\\Y_{a2}^{''}=L_{2}\cdot \sin( \theta _{1} + \theta _{2})\end{matrix}\right.

 - \left\{\begin{matrix}X_{a2}=L_{1}\cdot \cos( \theta _{1} )+L_{2}\cdot \cos( \theta _{1} + \theta _{2})\\Y_{a2}=L_{1}\cdot \sin( \theta _{1})+L_{2}\cdot \sin( \theta _{1} + \theta _{2})\end{matrix}\right.

 - https://latex.codecogs.com/svg.image?\theta_{3}

 - https://latex.codecogs.com/svg.image?\left\{\begin{matrix}x=L_{1} + L_{2}\cdot \cos(\theta _{2})\\y=L_{2}\cdot \sin(\theta _{2})\\z=0\end{matrix}\right.

 - https://latex.codecogs.com/svg.image?\begin{bmatrix}x^{'}\\y^{'}\\z^{'}\end{bmatrix} = \begin{bmatrix}1&0&0\\0&cos( \theta _{3} )&-sin( \theta _{3} )\\0&sin( \theta _{3})&cos( \theta _{3} )\end{bmatrix} \begin{bmatrix}x\\y\\z\end{bmatrix}=\begin{bmatrix}1&0&0\\0&cos( \theta _{3} )&-sin( \theta _{3}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

 - https://latex.codecogs.com/svg.image?\begin{bmatrix}x^{'}\\y^{'}\\z^{'}\end{bmatrix} = \begin{bmatrix}L_{1} + L_{2}\cdot \cos(\theta _{2})\\L_{2}\cdot\cos(\theta _{3})\cdot\sin(\theta _{2})\\L_{2}\cdot\sin(\theta _{2})\cdot\sin(\theta _{3})\end{bmatrix}

 - https://latex.codecogs.com/svg.image?\begin{bmatrix}x^{''}\\y^{''}\\z^{''}\end{bmatrix} = \begin{bmatrix}cos( \theta _{1} )&-sin( \theta _{1} )&0\\sin( \theta _{1})&cos( \theta _{1} )&0\\0&0&1\end{bmatrix} \begin{bmatrix}x^{'}\\y^{'}\\z^{'}\end{bmatrix}=\begin{bmatrix}cos( \theta _{1} )&-sin( \thet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

 - http://latex.codecogs.com/svg.latex?\left\{\begin{matrix}x^{2}+y^{2}+z^{2}=L_{1}^{2}\\(x-x_{0})^{2}+(y-y_{0})^{2}+(z-z_{0})^{2}=L_{2}^{2}\end{matrix}\right.

 - http://latex.codecogs.com/svg.latex?x^{2}-2xx_{0}+x_{0}^{2}+y^{2}-2yy_{0}+y_{0}^{2}+z^{2}-2zz_{0}+z_{0}^{2}=L_{2}^{2}

 - http://latex.codecogs.com/svg.latex?-2xx_{0}-2yy_{0}-2zz_{0} - L_{2}^{2} + L_{1}^{2} + d=0

 - http://latex.codecogs.com/svg.latex? - L_{2}^{2} + L_{1}^{2} + d

 - http://latex.codecogs.com/svg.latex?Ax + By + Cz + D=0

 - http://latex.codecogs.com/svg.latex?\left\{\begin{matrix}x^{2}+y^{2}+z^{2}=L_{1}^{2}\\Ax + By + Cz + D=0\\z=0\end{matrix}\right.

 - http://latex.codecogs.com/svg.latex?\left\{\begin{matrix}x^{2}+y^{2}=L_{1}^{2}\\Ax + By + D=0\end{matrix}\right.

 - http://latex.codecogs.com/svg.latex?x = \frac{-D-By}{A}

 - http://latex.codecogs.com/svg.latex?(\frac{-D-By}{A})^{2}+y^{2}=L_{1}^{2}

 - https://latex.codecogs.com/svg.image?(\frac{D}{A}+\frac{B}{A}y)^{2}+y^{2}=L_{1}^{2}

 - https://latex.codecogs.com/svg.image?(\frac{D}{A})^{2}+2\frac{D}{A}\frac{B}{A}y+(\frac{B}{A}y)^{2}+y^{2}=L_{1}^{2}

 - https://latex.codecogs.com/svg.image?D^{2}+2DBy+B^{2}y^{2}+A^{2}y^{2}=A^{2}L_{1}^{2}

 - https://latex.codecogs.com/svg.image?(A^{2}+B^{2})y^{2}+2DBy+(D^{2}-A^{2}L_{1}^{2})=0

 - https://latex.codecogs.com/svg.image?\theta _{1}=\arctan(\frac{y_{m}}{x_{m}})

 - https://latex.codecogs.com/svg.image?\left| \begin{matrix}x-x_1&y-y_1&z-z_1\\ x_2-x_1&y_2-y_1&z_2-z_1\\ x_3-x_1&y_3-y_1&z_3-z_1\\ \end{matrix}\right|=0.

 - https://latex.codecogs.com/svg.image?x_{1-3}, y_{1-3}, z_{1-3}

 - https://latex.codecogs.com/svg.image?z_{0}y_{m}x + (-z_{0}x_{m})y +(-x_{0}y_{m}+x_{m}y_{0})z = 0

 - https://latex.codecogs.com/svg.image?\cos(\alpha )=\frac{\left|(x_{1}x_{2}+y_{1}y_{2}+z_{1}z_{2})\right|}{\sqrt{x_{1}^{2}+y_{1}^{2} + z_{1}^{2}}\sqrt{x_{2}^{2}+y_{2}^{2} + z_{2}^{2}}}

 - https://latex.codecogs.com/svg.image?\cos(\alpha )=\frac{(x_{1}x_{2}+y_{1}y_{2}+z_{1}z_{2})}{\sqrt{x_{1}^{2}+y_{1}^{2} + z_{1}^{2}}\sqrt{x_{2}^{2}+y_{2}^{2} + z_{2}^{2}}}

 - https://latex.codecogs.com/svg.image?\cos(\theta_{3})=\frac{-(x_{0}y_{m}-x_{m}y_{0})}{\sqrt{(x_{m}z_{0})^{2}+(y_{m}z_{0})^{2} + (x_{0}y_{m}-x_{m}y_{0})^{2}}}

 - https://latex.codecogs.com/svg.image?\cos(\theta_{3})=\sin(\frac{\pi }{2}-\theta_{3})

 - https://latex.codecogs.com/svg.image?\sin(\arctan(\alpha ))=\frac{\alpha }{\sqrt{1+\alpha ^{2}}}

 - https://latex.codecogs.com/svg.image?\frac{-(x_{0}y_{m}-x_{m}y_{0})}{\sqrt{(x_{m}z_{0})^{2}+(y_{m}z_{0})^{2} + (x_{0}y_{m}-x_{m}y_{0})^{2}}}=\frac{-(x_{0}y_{m}-x_{m}y_{0})}{\sqrt{(x_{m}z_{0})^{2}+(y_{m}z_{0})^{2}}\sqrt{1 + \frac{(x_{0}y_{m}-x_{m}y_{0})^{2}}{(x_{m}z_{0})^{2}+(y_{m}z_{0})^{2}}}

 - https://latex.codecogs.com/svg.image?\frac{-(x_{0}y_{m}-x_{m}y_{0})}{\sqrt{(x_{m}z_{0})^{2}+(y_{m}z_{0})^{2}}\sqrt{1 + (\frac{(x_{0}y_{m}-x_{m}y_{0})}{\sqrt{(x_{m}z_{0})^{2}+(y_{m}z_{0})^{2}}})^{2}}}=\frac{\frac{-(x_{0}y_{m}-x_{m}y_{0})}{\sqrt{(x_{m}z_{0})^{2}+(y_{m}z_{0})^{2}}}}{\sqrt{1 + (\frac{-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

 - https://latex.codecogs.com/svg.image?\frac{\pi}{2}-\theta_{3}=\arctan(\frac{-(x_{0}y_{m}-x_{m}y_{0})}{\sqrt{(x_{m}z_{0})^{2}+(y_{m}z_{0})^{2}}})

 - https://latex.codecogs.com/svg.image?\theta_{3}=\frac{\pi}{2}-\arctan(\frac{-(x_{0}y_{m}-x_{m}y_{0})}{\sqrt{(x_{m}z_{0})^{2}+(y_{m}z_{0})^{2}}})

 - \beta

 - r^2 = L_{1}^2 + L_{2}^2 -2\cdot L_{1} \cdot L_{2} \cdot \cos \beta

 - https://latex.codecogs.com/svg.image?\beta = \arccos(\frac{L_{1}^2 + L_{2}^2 - r^2}{2\cdot L_{1} \cdot L_{2}})

 - https://latex.codecogs.com/svg.image?r^2

 - https://latex.codecogs.com/svg.image?d

 - \theta_{2} = \pi - \arccos(\frac{L_{1}^2 + L_{2}^2 - d}{2\cdot L_{1} \cdot L_{2}})

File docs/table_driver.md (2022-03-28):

| Название | Пиковый ток, А | Рабочий ток, А | Наличие развязки | Цена, р | Ссылка на магазин |
| :---: | :---: | :---: | :---: | :-----: | :---: |
| Mosfet driver V3 | 22 | 5 | + | 245 | [Робопартс](https://roboparts.ru/catalog/drayvery/drayvery_dvigateley/mosfet-driver-v3/) |
| BTS7960 | 43 | 10 | - | 182 | [Алиэкспресc](https://aliexpress.ru/item/1005001631113020.html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) /  [Робошоп](https://roboparts.ru/catalog/drayvery/drayvery_dvigateley/modul-bts7960-driver/) |
| XY-160D | 50 | 7 | + | 500 | [Алиэкспресс](https://aliexpress.ru/item/1005002737147631.html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) |
| DBH-12V | 30 | 15 | - | 940 | [Алиэкспресс](https://aliexpress.ru/item/32941660566.html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,scm-url:1007.34525.239210.0,pvid:ab7ce18c-a944-47e6-ade5-f56e3c4861aa,tpp_buckets:24525%230%23239210%2333_21387%230%23233228%2341_4452%230%23226710%230_4452%233474%2315675%23116_4452%234862%2324463%23427_4452%233098%239624%23935_4452%235105%2323438%23529_4452%233564%2316062%23176&scenario=pcDetailBottomMoreOtherSeller&tpp_rcmd_bucket_id=239210) |
| D2810 | 15 | 10 | + | 164 | [Алиэкспресс](https://aliexpress.ru/item/4000071667611.html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) |
| IRF3205 | 30 | 15 | - | 770 | [Алиэкспресс](https://aliexpress.ru/item/32855292780.html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,searchweb201602_,searchweb201603_) |
| LR7843 | 150 | 20 | - |  1900 | [ELECHOUSE](http://www.elechouse.com/elechouse/index.php?main_page=product_info&products_id=2179) |  |

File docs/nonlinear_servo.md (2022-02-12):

# Нелинейность сервопривода

Для измерения нелинейности сервопривода использовался транспортир. На вал сервы была закреплена стрелка. При изменении скважности Δ = 50, записывались изменения угла. 
Изменение угла - это разность между предыдущим и текущим углом поворота сервы. 
Цикл 1 - это изменение скважности от 900 до 2100. 
Цикл 2 - это изменение скважности от 2100 до 900. 
Цикл 3 - это изменение скважности от 900 до 2100.

### Таблица изменений угла поворота

| № | Изменение угла, град (цикл 1) | Изменение угла, град (цикл 2) | Изменение угла, град (цикл 3) |
|---|:---:|---|---|
| 1 | 12 | 13 | 12 |
| 2 | 11 | 10 | 10 |
| 3 | 9 | 12 | 11 |
| 4 | 12 | 11 | 12 |
| 5 | 12 | 13 | 13 |
| 6 | 12 | 12 | 12 |
| 7 | 12 | 13 | 11 |
| 8 | 13 | 9 | 10 |
| 9 | 9 | 9 | 10 |
|10 | 11 | 10 | 10 |
|11 | 9 | 8 | 9 |
|12 | 8 | 10 | 10 |
|13 | 10 | 9 | 9 |
|14 | 10 | 12 | 12 |
|15 | 11 | 10 | 10 |
|16 | 10 | 12 | 11 |
|17 | 12 | 12 | 13 |
|18 | 13 | 8 | 10 |
|19 | 10 | 12 | 10 |
|20 | 12 | 9 | 12 |
|21 | 12 | 11 | 11 |
|22 | 10 | 9 | 10 |
|23 | 10 | 11 | 9 |
|24 | 8 | 9 | 10 |
|25 | 11 | 12 | 11 |

### Вывод
Как видно из таблицы, при приращении скважности 50, максимальное отклонение угла поворота составляет 5 градусов. Одной из причин разных углов поврота при одинаковом приращении скважности может быть то, что стрелка на валу закреплена не жестко, а также присутствует зрительная погрешность. Эксперимент проводился без нагрузки.

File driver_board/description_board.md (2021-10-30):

 # Плата драйвера для ДПТ
 
### Габариты: 

        -ширина: 80.5 мм.
        -длина: 70 мм.

### Монтажные отверстия: 

        -количество: 4 шт.
        -диаметр: 3мм.
        
### Перечень элементов:
                            
| Позиционное обозначение | Наименование | Кол-во |
|---|---|---|
| С1-2 | Конденсатор 16В, 10мкФ (smd) | 2 |
| С3-4 | Конденсатор 16В, 47мкФ (smd) | 2 |
| C5 | Конденсатор 26В, 220мкФ | 1 |
| D1-6 | Диод SOD123 (smd) | 6 |
| F1 | Предохранитель | 1 |
| R1-4 | Резисторы 1206, 10 Ом (smd)  | 4 |
| R5-8 | Резисторы 1206, 1 кОм (smd)  | 4 |
| U1-4 | Мосфет IRF2807S (smd) | 4 |
| X1-2 | Драйвер IR2101S (smd) | 2 |
| P1 | JST разъем 5 pin | 1 |

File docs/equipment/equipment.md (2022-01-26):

Миша

# Части робота
Робот состоит из трех частей: 
- основание; 
- туловище;
- голова.

## Описание периферии нижнего уровня

### Описание основания
Основание состоит из:
- 3 электродвигателя;
    - Номинальное напряжение 12В и мощностью 150Вт (см. папку с фото). Ток удержания (блокировка вращения) достигал значние 20А.
    <details><summary>Фото</summary>

    Привод перемещения
    </details>

- 3 оптических энкодера:
    - На диске энкодера 20 засечек, шаг квантования 18 градусов при работе по фронту, 9 градусов при работе по фронту и срезу.
    <details><summary>Фото</summary>
    
    Оптический энкодер в основании
    </details>

- 3 инфракарсный датчика расстояния **sharp gp2d12** [Ссылка на DS](https://engineering.purdue.edu/ME588/SpecSheets/sharp_gp2d12.pdf);

- 4 ультразвуковых датчика расстояния **jsn-sr04t** [Ссылка на DS](https://www.makerguides.com/wp-content/uploads/2019/02/JSN-SR04T-Datasheet.pdf);

    <details><summary>Фото</summary>

    Ультразвуковой датчик расстояния
    </details>

- uart-приемник 

### Описание туловища 
Туловище состоит из:
- 4 энкодера hae18u5v12a0.5 [Ссылка на DS](https://www.amazon.com/Resolution-Magnetic-Rotary-Encoder-Absolute/dp/B07QJ8S3JM);
    <details><summary>Фото</summary>

    Энкодер рука_1
    Энкодер рука_2
    Энкодер рука_3
    </details>

- 4 серво SRS-3216HTG [Ссылка на DS](https://cdn-global-hk.hobbyking.com/media/file/14371476X1921611X26.pdf);

    - Один серво управляет хватом, второй вращает хват вокруг своей оси. 
    - Возможный ход 270 градусов, с длительностью управляющих импульсов 0.9-2.1мс. 
    - Серво в кисти имеет механические ограничения. 
    - Допустимы диапазон работы соответствует диапазону импульсов 1.11-1.62мс. В случае выхода из диапазона ток удержания по даташиту порядка 6А. 
    > ⚠️ В одной из рук не работает серво в локте, возможно механически заблокирован.
    <details><summary>Фото</summary>

    Серво на руке
    </details>

- 2 привода линейного перемещения;
    - Привод установлен на плече робота. Отвечает за поднятие предплечья. 
    - Номинальное напряжение 12В.
    - Ток без нагрузки 0.7А, с нагрузкой в 3.140 кг. ток - 2.4А.
    - При последниех замерах уходил в насыщение по току - 1.4А и уже не мог поднять груз.

    <details><summary>Фото</summary>

    Информация о линейном приводе
    </details>

- 4 двигателя **s150106xd88**;
    - Приводы стоят внутри робота. 
    - Один отвечает за поворот плеча, другой за поднятие руки.
    - Номинальное напряжение 12В. 
    - Ток без нагрузки 0.8А, с нагрузкой в 3.140 кг. ток - 1.4А. 
    - Ток удержания (блокировка вращения) достигал значние 7А.
    
    <details><summary>Фото</summary>

    Привод поворота руки
    </details>

### Описание головы 
Голова состоит из:
- 4 серво **HXT900HEXTRONIK** [Ссылка на DS](http://electronics.inf.ua/P36.files/Hextronik_HXT900.pdf);
    <details><summary>Фото</summary>

    Серво в голове
    </details>
- 1 серво **h king hk15138** [Ссылка на DS](http://www.agspecinfo.com/pdfs/H/HK15138.PDF);

## Описание периферии верхнего уровня

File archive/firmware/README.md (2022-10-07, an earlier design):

### TARGET

The firmware runs on an STM32 Nucleo64-F411RE board.

### Useful links
* [Reference manual (RM)](https://www.st.com/resource/en/user_manual/um1724-stm32-nucleo64-boards-mb1136-stmicroelectronics.pdf)
* [Datasheet (DS)](https://www.st.com/resource/en/data_brief/nucleo-f411re.pdf)
* [Nucleo pinout](https://os.mbed.com/platforms/ST-Nucleo-F411RE/)

### Notes

Based on demos from https://github.com/ChibiOS/ChibiOS

### Information for developers

* При работе с энкодером было замечено, что первый полученный бит является незначащим, эта информация не указана в DataSheet на данный энкодер.

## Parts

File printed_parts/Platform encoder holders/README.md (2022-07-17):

# Крепление для инкрементального энкодера в основнии робота

Крепление состоит из двух частей: нижняя крепится к основанию робота, верхняя фиксирует крепление. Из-за не самых прямых рук отверстия для двух энкодеров сделаны со смещением, поэтому две разные модельки нижней части крепления

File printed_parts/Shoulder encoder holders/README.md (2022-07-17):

# Крепление для абсолютного энкодера в плечевом суставе робота

Крепление нужно чтобы не дать корпусу энкодера прокручиваться при повороте руки. Левое и правое крепление симметричны и сделаны из одного исходника с помощью зеркального отражения

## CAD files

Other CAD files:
printed_parts/Platform encoder holders/bot_part_symmetrical.SLDPRT
printed_parts/Shoulder encoder holders/shoulder_encoder_holder_left.STL
printed_parts/Platform encoder holders/bot_part_shifted.SLDPRT
printed_parts/Shoulder encoder holders/shoulder_encoder_holder.SLDPRT
printed_parts/Platform encoder holders/top_part.SLDPRT
printed_parts/Shoulder encoder holders/shoulder_encoder_holder_right.STL
printed_parts/Platform encoder holders/bot_part_shifted.STL
printed_parts/Platform encoder holders/bot_part_symmetrical.STL
printed_parts/Platform encoder holders/top_part.STL

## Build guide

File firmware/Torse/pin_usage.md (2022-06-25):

# Использование модулей периферии контроллера

| Pin | Назначение |
|---|---|
| PE13  | левый локоть(PWM) |
| PB1 | левый локоть вверх |
| PB15  | левый локоть вниз |
| PE9 | левое плечо(IN) поступательное (PWM) |
| PC8 | левое плечо(IN) вверх |
| PE14  | левое плечо(IN) вниз |
| PE11  | левое плечо(OUT) вращательное(PWM) |
| PA5 | левое плечо(OUT) вверх |
| PB0 | левое плечо(OUT) вниз |
| PC9 | правый локоть(PWM) |
| PD13  | правый локоть вверх |
| PB2 | правый локоть вниз |
| PC6 | правое плечо(IN) поступательное(PWM) |
| PE10  | правое плечо(IN) вверх |
| PE12  | правое плечо(IN) вниз |
| PC7 | правое плечо(OUT) вращательное(PWM)  |
| PD11  | правое плечо(OUT) вверх |
| PD12  | правое плечо(OUT) вниз |
| PA6 | MISO (SPI1) левая рука |
| PB3 | CLK (SPI1) левая рука |
| PC2 | MISO (SPI2) правая рука |
| PD3 | CLK (SPI2) правая рука |
| PA3 | CS левый локоть |
| PA4 | CS правый локоть |
| PC0 | CS левое плечо (IN) поступательное |
| PG0 | CS правое плечо (IN) поступательное  |
| PG2 | CS левое плечо (OUT) вращательное |
| PG3 | CS правое плечо (OUT) вращательное |
| PB5 | сервопривод right_wrist (PWM) |
| PB6 | сервопривод left_hand (PWM) |
| PB8 | сервопривод left_wrist (PWM) |
| PB9 | сервопривод right_hand (PWM) |

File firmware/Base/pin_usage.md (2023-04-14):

# Использование модулей периферии контроллера в основании

| Pin  | Назначение |
|---|---|
| PA4  | Энкодер 1, фаза А |
| PA3  | Энкодер 1, фаза Б |
| PF3  | Энкодер 2, фаза А |
| PF5  | Энкодер 2, фаза Б |
| PF1  | Энкодер 3, фаза А |
| PF2  | Энкодер 3, фаза Б |
| PE11 | Мотор 1, HIN1 |
| PE10 | Мотор 1, LIN1 |
| PE13 | Мотор 1, HIN2 |
| PE12 | Мотор 1, LIN2 |
| PC6  | Мотор 2, HIN1 |
| PA5  | Мотор 2, LIN1 |
| PC7  | Мотор 2, HIN2 |
| PB0  | Мотор 2, LIN2 |
| PC8  | Мотор 3, HIN1 |
| PB1  | Мотор 3, LIN1 |
| PE9  | Мотор 3, HIN2 |
| PE8  | Мотор 3, LIN2 |
| PB8  | Гироскоп, SCL |
| PB9  | Гироскоп, SDA |

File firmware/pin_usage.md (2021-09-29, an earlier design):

#Использование модулей периферии контроллера

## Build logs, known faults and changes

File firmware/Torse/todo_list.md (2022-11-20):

Что необходимо сделать:
- Калибровка углов с записью во флеш;
- Сделать проект для тестов модулей, которые не привязаны к железу;
- Документация.

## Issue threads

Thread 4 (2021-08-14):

Сделать первый вариант архитектуры решения

KaiL4eK, 2021-08-14:
После составления списка модулей #2 нужно разработать архитектуру решения, которое будем реализовывать

serykhelena, 2022-10-22:
Всё в Wiki - https://github.com/lsd-maddrive/mishanya-bot-project/wiki/Plans

Closed 2022-10-22.

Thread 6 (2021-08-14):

Сделать фото и замер основных размеров и составить схему размеров робота

KaiL4eK, 2021-08-14:
Нужно для описания сделать несколько фотографий и замерить основные размеры робота:
- габариты
- размеры базы
- длина руки всей и каждого звена
- высота нижней точки туловища над базой
- высота, ширина туловища
- другие...

Closed 2021-09-22.

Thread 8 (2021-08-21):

Определить пиковые токи двигателей

KaiL4eK, 2021-08-21:
Нужно через лаб. блок понять, какие токи потребляют двигатели на 12 В. Обязательно постараться провода как можно короче сделать, чтобы не было сильных потеть.

Closed 2021-08-29.

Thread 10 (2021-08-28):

Сформулировать улучшения по плате драйверов от бб-ки

serykhelena, 2021-08-28:
Есть мысль использовать плату драйверов от бб-ки для мишани.
Улучшать плату будет Павел, нужно подготовить исправления так, чтобы он мог разобраться что, как и где улучшать (с блэкджеком и картинками)

Closed 2021-09-14.

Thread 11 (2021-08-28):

Поиск готовых плат-драйверов для ДПТ

serykhelena, 2021-08-28:
Нужно подготовить таблицу в формате .md (в папке /docs) с ссылками на магазины (например, Алиэкспресс, Чип и Дип, etc). Где, какие драйвера есть.

То есть таблица может иметь следующие колонки:
* Название драйвера (или обобщённое название, не обязательно все серии перечислять)
* Пиковый ток (А)
* ~Цена
* Ссылка, где можно купить

Интересны драйвера с:
* током в нормальном режиме: 4 - 5 А
* с радиатором
* мощность 50-60 Вт

Closed 2021-09-12.

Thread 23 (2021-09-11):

Разработка драйвера ДПТ

Doraepod, 2021-09-11:
Задача разработать 3 версии драйвера:
  - Без радиатора
  - С радиатором
  - Без радиатора, с логикой
Разные варианты стоит делать последовательно, и полностью решить все сложности с первой версией, прежде чем приступать ко второй.

На что обращать внимание:

1) Наличие паразитных индуктивностей при сложных путях дорожек. На [Хабре](https://habr.com/ru/post/414141/) есть вроде бы дельная статья по разводке, но без фанатизма.
2) Силовые дорожки делать **ЖИРНЫМИ** и не покрывать лаком. Самый минимум - 6мм.
3) Разделить цифровую и силовую часть. То есть входы с мк с одной стороны, силовые контакты с другой. Для цифровой части использовать угловой JST, для силовых выводов оставить металлизированные отверстия диаметром 3мм.
4) Монтажные отверстия изолированы от земли/дорожек.
5) Печатать разведенную плату на бумаге (в масштабе 1к1) и прикладывать элементы.
6) Шелкография. Должно быть очевидно к какому элементу относится подпись. Наличие ключа для всех элементов, где это применимо.

KaiL4eK, 2021-09-22:
До конца недели

serykhelena, 2021-11-08:
@pavelrepin99 @Doraepod А эта задача ещё не закончена? Вроде же уже платы заказаны?

Doraepod, 2021-11-08:
@serykhelena Закончена, уже все едет

Closed 2021-11-08.

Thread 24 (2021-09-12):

Кинематическая модель робота

ilmirgogorev, 2021-09-12:
Кинематическая модель руки-манипулятора:
1. Обмерить габариты элементов звеньев руки манипулятора
2. Рассчитать передачу от перемещения линейного двигателя к угловому перемещению плеча + проверить измерение энкодеров
3. Измерить пределы перемещения линейного двигателя, поворота плечевого сустава, размаха клешни
Кинематическая модель основания:
1. Померить радиус колёс
2. Померить радиус основания(расстояние от колеса до центра)

KaiL4eK, 2021-09-22:
- [ ] Измерить руку
- [ ] Измерить основание

KaiL4eK, 2021-09-22:
До конца недели

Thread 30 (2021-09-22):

Исследовать вопрос взаимдействия SPI и I2C в Chibi

KaiL4eK, 2021-09-22:
Было замечено, что модули конкурируют и приводят к коллизии.

Doraepod, 2021-09-25:
Эксперимент показал, что проблем нет. Сложности могут возникнуть из-за пересечений DMA каналов.

Closed 2021-09-25.

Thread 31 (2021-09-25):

Проверить линейность драйвера

adhelll, 2021-09-25:
Необходимо:
- подключить энкодеры в основании;
- снять зависимость скорости движка от коэффициента заполнения ШИМ сигнала;
- определить нелинейность драйвера.

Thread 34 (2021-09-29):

Закупка комплектующих

Doraepod, 2021-09-29:
2 энкодера CALT HAE18 12 для плечевых суставов.

  - https://www.amazon.com/gp/product/B01DPAR4AA
  - https://aliexpress.ru/item/32988910239.html
  - https://aliexpress.ru/item/1214295061.html

Doraepod, 2022-03-20:
Куплено

Closed 2022-03-20.

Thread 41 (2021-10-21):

Разработка LLD-драйвера для сервоприводов в хвате робота

serykhelena, 2021-10-21:
* Без системы управления
* функционал по заданию ШИМ сигнала с защитой "от дурака" (чтобы не доспустить выхода за пределы ШИМ)

serykhelena, 2021-10-21:
https://github.com/lsd-maddrive/mishanya-bot-project/blob/develop/docs/equipment/equipment.md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 Здесь есть величины крайних значений для серв

Closed 2022-01-26.

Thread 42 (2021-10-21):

Разработка системы управления сервоприводами в хвате робота

serykhelena, 2021-10-21:
* Основа системы управления на основе ПИД (по необходимости составляющие отключить) регулятора.
* Проверить что там по обратной связи, возможно, нужно будет вывести провод потенциометра из серв

serykhelena, 2022-02-12:
По исследованию нелинейности серва отрабатывает стабильно, пока замкнутую СУ делать смысла нет

Closed 2022-02-12.

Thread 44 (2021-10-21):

Оценить нелинейность сервопривода в хвате робота

serykhelena, 2021-10-21:
Разработать мини-стенд для измерения отношения сигнала (скважности ШИМ) к углу.
На вал сервы можно прилепить стрелку и распечатать шкалу транспортира - таким образом измерять угол поворота.

Необходимо понять, а нужна ли внешняя СУ для сервопривода, т.е. как сильно гуляют значения без нагрузки и с нагрузкой, и т.п.

serykhelena, 2022-03-19:
был разработан код теста, серва ведёт себя стабильно, СУ пока делать нет смысла

Closed 2022-03-19.

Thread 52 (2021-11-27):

Проверка драйверов 1-го колеса

serykhelena, 2021-11-27:
Пока достаточно проверить 1 колесо при помощи теста из STM 767 и bb-драйвера

Пины для 1-го колеса (PWM 1)
MOTOR1_PWM_LINE_HIN1    PAL_LINE(GPIOE, 11)
MOTOR1_PWM_LINE_LIN1    PAL_LINE(GPIOE, 10)
MOTOR1_PWM_LINE_HIN2    PAL_LINE(GPIOE, 13)
MOTOR1_PWM_LINE_LIN2    PAL_LINE(GPIOE, 12)

serykhelena, 2023-03-17:
Сделано

Closed 2023-03-17.

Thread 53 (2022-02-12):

Адаптировать прошивку STM F411 для STM 767ZI

serykhelena, 2022-02-12:
Нужно сделать единую прошивку. В роботе будет стоять 2 стм-ки 767, одна в нижнем основании, вторая в теле, между собой они будут соединены через CAN.
То есть нужно взять код Антона, "переписать" его для СТМ 767, разобраться в нём, особенно в коде для силовых драйверов. Проверить, что все тесты работают.

KaiL4eK, 2022-05-14:
@serykhelena  это готово

serykhelena, 2022-05-14:
готово

Closed 2022-05-14.

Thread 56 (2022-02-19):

Подключить драйвера в нижнем основании

serykhelena, 2022-02-19:
Нужно подключить все платы, организовать провода удобно и безопасно.
Перед тем как крутить колёса, проверить всё на осциллографе, проверить, что все колёса крутятся по всех направлениях.
Управление через lld_bb_driver

serykhelena, 2022-10-22:
Дубликат задачи #68

Closed 2022-10-22.

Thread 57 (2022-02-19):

Драйвер энкодера для нижнего основания

serykhelena, 2022-02-19:
Скорее всего энкодеры будем менять

Но нужен модуль, который умеет:
- выдавать кол-во тиков
- выдавать кол-во оборотов
- выдавать направление вращения
- функция для сброса (reset)

Closed 2022-07-22.

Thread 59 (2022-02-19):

СУ по скорости для колеса в нижнем основании

serykhelena, 2022-02-19:
Нужно разработать замкнутую СУ по скорости для колеса в нижнем основании.
То есть задаём "Колесо, крутись со скоростью 2 км/ч" и колесо отрабатывает это **с нагрузкой**

Closed 2023-03-27.

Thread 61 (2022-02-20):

Определиться с механикой энкодера на колеса

KaiL4eK, 2022-02-20:

serykhelena, 2022-02-21:
- https://aliexpress.ru/item/1005003061099669.html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
- https://aliexpress.ru/item/1279218186.html?spm=a2g2w.detail.1000060.3.210638cdaRZIlg&_evo_buckets=165609,165598,188871,224373,176818,194275&sku_id=5439334775&gps-id=aerPdpSubstituteRcmd&scm=1007.34525.266934.0&scm_id=1007.34525.266934.0&scm-url=1007.34525.266934.0&pvid=c7589e34-b998-4cff-8319-a2a3104fe8c5&_t=gps-id:aerPdpSubstituteRcmd,scm-url:1007.34525.266934.0,pvid:c7589e34-b998-4cff-8319-a2a3104fe8c5,tpp_buckets:24525%230%23266934%233_21387%230%23233228%238&scenario=aerPdpSubstituteRcmd&tpp_rcmd_bucket_id=266934
- https://www.chipdip.ru/product/heds-5540-a11-1

KaiL4eK, 2022-02-25:
Последний не работает

KaiL4eK, 2022-02-25:
Чет кажется, что надо первый заказывать

serykhelena, 2022-03-12:
Вроде определились, что через ремни

Closed 2022-03-12.

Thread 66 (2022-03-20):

Спланировать подключение рук на F767ZI

KaiL4eK, 2022-03-20:
Из-за блокировок основная страница с Pinout заблокирована (https://os.mbed.com/platforms/ST-Nucleo-F767ZI/) - выгрузил картинки и datasheet сюда: https://disk.yandex.ru/d/VdiUvhrjdGQnWQ

Задача - спланировать, сколько и на какие ноги подключаем драйверы.
Насколько я помню, для BB нужно 4 ноги в комплементарном режиме. То есть, всего 12 ног - 3 таймера надо найти.

Питание, полагаю, будем брать от лабораторного источника.

serykhelena, 2022-03-23:
Пины для 1-го движка (PWM 1)
MOTOR1_PWM_LINE_HIN1 PAL_LINE(GPIOE, 11)
MOTOR1_PWM_LINE_LIN1 PAL_LINE(GPIOE, 10)
MOTOR1_PWM_LINE_HIN2 PAL_LINE(GPIOE, 13)
MOTOR1_PWM_LINE_LIN2 PAL_LINE(GPIOE, 12)

Пины для 2-го движка (PWM 8)
MOTOR2_PWM_LINE_HIN1 PAL_LINE(GPIOC, 6)
MOTOR2_PWM_LINE_LIN1 PAL_LINE(GPIOA, 5)
MOTOR2_PWM_LINE_HIN2 PAL_LINE(GPIOC, 7)
MOTOR2_PWM_LINE_LIN2 PAL_LINE(GPIOB, 0)

Пины для 3-го движка (PWM1 + PWM8)
MOTOR3_PWM_LINE_HIN1 PAL_LINE(GPIOC, 8)
MOTOR3_PWM_LINE_LIN1 PAL_LINE(GPIOB, 1)
MOTOR3_PWM_LINE_HIN2 PAL_LINE(GPIOE, 9)
MOTOR3_PWM_LINE_LIN2 PAL_LINE(GPIOE, 8)

Doraepod, 2022-03-23:
Сверху все круто. Небольшой комментарий: для работы драйвера нужны 2 пары комплементарных ног, так что это всего два канала таймера. Но подойдет только advanced таймер, так что только 1 и 8. У каждого таймера по 4 канала, так что двумя таймерами справляемся и даже два канала остаются свободными. Но на вторую руку стм точно не хватит, разве что переписывать логику под обычные таймеры.

serykhelena, 2022-03-23:
@Doraepod можешь подготовить пины для красного драйвера?

Doraepod, 2022-03-25:
Думаю логично по максимум использовать те-же ноги, чтобы конфликтов поменьше было. Тогда на шесть драйверов будет так:
Левое плечо 1
PWM    GPIOE 8 TIM1_CH1
PIN1    GPIOC 8
PIN2    GPIOE 14

Левое плечо 2
PWM    GPIOE 11 TIM1_CH2
PIN1    GPIOA 5
PIN2    GPIOB 0

Левый локоть
PWM    GPIOE 13 TIM1_CH3
PIN1    GPIOB 1
PIN2    GPIOB 15

Правое плечо 1
PWM    GPIOC 6 TIM8_CH1
PIN1    GPIOE 10
PIN2    GPIOE 12

Правое плечо 2
PWM    GPIOC 7 TIM8_CH2
PIN1    GPIOD 11
PIN2    GPIOD 12

Правый локоть
PWM    GPIOC 9 TIM8_CH3
PIN1    GPIOD13
PIN2    GPIOB 2

Это все каналы первого и восьмого таймеров, включая комплиментарные, и какие-то четыре ноги, которые мне показались свободными. На них висят из интересного spi3, i2c4, канала четвертого таймера. PWM ноги должны работать в режиме канала таймера, остальные просто на выход.

serykhelena, 2022-03-30:
Спланировано

Closed 2022-03-30.

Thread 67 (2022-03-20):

Кинематика рук на Си

Doraepod, 2022-03-20:
Координаты и углы хранить в структурах, заданных через typedef. Функция обратной кинематики должна принимать структуру с координатами или указатель на нее и возвращать структуру с углами, или указатель на нее.

Closed 2022-11-20.

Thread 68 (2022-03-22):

Проверить все колёса с драйверами [LLD]

serykhelena, 2022-03-22:
Добавить дефайны для тестов остальных колёс и проверить все 3 колеса

Пины для 1-го колеса (PWM 1)
MOTOR1_PWM_LINE_HIN1 PAL_LINE(GPIOE, 11)
MOTOR1_PWM_LINE_LIN1 PAL_LINE(GPIOE, 10)
MOTOR1_PWM_LINE_HIN2 PAL_LINE(GPIOE, 13)
MOTOR1_PWM_LINE_LIN2 PAL_LINE(GPIOE, 12)

Пины для 2-го колеса (PWM 8)
MOTOR2_PWM_LINE_HIN1    PAL_LINE(GPIOC, 6)
MOTOR2_PWM_LINE_LIN1    PAL_LINE(GPIOA, 5)
MOTOR2_PWM_LINE_HIN2    PAL_LINE(GPIOC, 7)
MOTOR2_PWM_LINE_LIN2    PAL_LINE(GPIOB, 0)

Пины для 3-го колеса (PWM1 + PWM8)
MOTOR3_PWM_LINE_HIN1    PAL_LINE(GPIOC, 8)
MOTOR3_PWM_LINE_LIN1    PAL_LINE(GPIOB, 1)
MOTOR3_PWM_LINE_HIN2    PAL_LINE(GPIOE, 9)
MOTOR3_PWM_LINE_LIN2    PAL_LINE(GPIOE, 8)

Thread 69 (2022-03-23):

Адаптировать прошивку STM F411 для STM 767ZI для одной руки

serykhelena, 2022-03-23:
Для bb_driver

Пины для 1-го движка (PWM 1)
MOTOR1_PWM_LINE_HIN1 PAL_LINE(GPIOE, 11)
MOTOR1_PWM_LINE_LIN1 PAL_LINE(GPIOE, 10)
MOTOR1_PWM_LINE_HIN2 PAL_LINE(GPIOE, 13)
MOTOR1_PWM_LINE_LIN2 PAL_LINE(GPIOE, 12)

Пины для 2-го движка (PWM 8)
MOTOR2_PWM_LINE_HIN1 PAL_LINE(GPIOC, 6)
MOTOR2_PWM_LINE_LIN1 PAL_LINE(GPIOA, 5)
MOTOR2_PWM_LINE_HIN2 PAL_LINE(GPIOC, 7)
MOTOR2_PWM_LINE_LIN2 PAL_LINE(GPIOB, 0)

Пины для 3-го движка (PWM1 + PWM8)
MOTOR3_PWM_LINE_HIN1 PAL_LINE(GPIOC, 8)
MOTOR3_PWM_LINE_LIN1 PAL_LINE(GPIOB, 1)
MOTOR3_PWM_LINE_HIN2 PAL_LINE(GPIOE, 9)
MOTOR3_PWM_LINE_LIN2 PAL_LINE(GPIOE, 8)

serykhelena, 2022-03-30:
Пока только прошивка с красным драйвером, для бб-драйвера нужна доработка кода

Closed 2022-05-05.

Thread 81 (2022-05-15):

Доработка драйвера Ethernet STM <-> PC

serykhelena, 2022-05-15:

serykhelena, 2022-07-09:
Чтобы включить `lwip` надо разархивировать соответствующий архив в папке `chibios203\ext`. Так же надо подключить исходник библиотеки evtimer в `makefile` или `project.mk`

```
CSRC = $(ALLCSRC) \
       $(TESTSRC) \
       $(PROJECT_CSRC) \
       $(CHIBIOS)/os/various/evtimer.c
```
И в `halconf.h` надо включить драйвер `MAC`

[Nucleo tcp server test.zip](https://github.com/lsd-maddrive/mishanya-bot-project/files/9077313/Nucleo.tcp.server.test.zip)

KaiL4eK, 2022-07-17:
В репо по чиби появились два примера по TCP

serykhelena, 2022-07-17:
https://github.com/lsd-maddrive/STM32_ChibiOS/tree/stable_20.3.x/HAL_examples/TCP-ROS-Link

https://github.com/lsd-maddrive/STM32_ChibiOS/tree/stable_20.3.x/HAL_examples/TCP/Nucleo_tcp_server_test

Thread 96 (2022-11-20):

Автоматическая калибровка углов

adhelll, 2022-11-20:
Требуется сделать так, чтобы углы, которые соответствуют крайним положениям рук хранились во flash памяти контроллера.
Должно быть предусмотрено несколько сценариев:
1) Если по указанным адресам flash памяти есть значения и нет сигнала (зажата кнопка пользователя перед стартом?) о том, что надо откалибровать углы, считаем данные из flash актуальными;
2) Если по указанным адресам flash памяти нет значений, то произвести запись во flash;
2) Если есть сигнал, то произвести запись углов во flash с возможным стиранием области, если данные там уже есть.

Closed 2023-03-25.

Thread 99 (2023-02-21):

Вопрос по обработке прерываний энкодера

Muzalevsky, 2023-02-21:
https://github.com/lsd-maddrive/mishanya-bot-project/blob/3786f07e95dbf1bda7ba5a31c26850f4168964b7/firmware/Base/src/encoder_base.c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

Есть вопрос к этой строке: что если `enc_t->tic_count = MAX_TIC + 10`, тогда мы потеряем 10 меток на оборот, что много. Если гарантируется обработка прерывания при прохождении одной метки `MAX_TIC`,то моя претензия не актуальна (можно больше убрать в таком случае).

Closed 2023-03-27.

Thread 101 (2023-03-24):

Разработка LLD блока обработки гироскопа

serykhelena, 2023-03-24:
- [x] Отдельно сделать файлы для работы с I2C [src/include] - можно списать [отсюда](https://github.com/lsd-maddrive/bb_project/blob/develop/controller_bb_8_driver/src/i2c.c)
- [x] start I2C
- [x] write bytes from slave
- [x] read bytes from slave
- [x] Инициализация модуля гироскопа
- [x] В отдельном потоке сделать интегрирование данных с гироскопа, чтобы получить угол. Угол должен быть в предалах [0, 360]. Если угол > 360, то обрубаем к 0-лю (т.е. angle -= 360). Если угол < 0, то angle += 360. Поток дёргаем каждые 5 мс
- [x] геттер - текущее значение угла в градусах по указанной оси
- [x] геттер - текущее значение угловой скорости по указанной оси [градус/с]

Closed 2023-04-14.

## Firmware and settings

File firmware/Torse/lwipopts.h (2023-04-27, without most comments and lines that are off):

#define __LWIPOPT_H__
#define SYS_LIGHTWEIGHT_PROT            0
#define NO_SYS                          0
#define NO_SYS_NO_TIMERS                0
#define MEMCPY(dst,src,len)             memcpy(dst,src,len)
#define SMEMCPY(dst,src,len)            memcpy(dst,src,len)
#define MEM_LIBC_MALLOC                 0
#define MEMP_MEM_MALLOC                 0
#define MEM_ALIGNMENT                   4
#define MEM_SIZE                        800
#define MEMP_SEPARATE_POOLS             0
#define MEMP_OVERFLOW_CHECK             0
#define MEMP_SANITY_CHECK               0
#define MEM_USE_POOLS                   0
#define MEM_USE_POOLS_TRY_BIGGER_POOL   0
#define MEMP_USE_CUSTOM_POOLS           0
#define LWIP_ALLOW_MEM_FREE_FROM_OTHER_CONTEXT 0
#define MEMP_NUM_PBUF                   16
#define MEMP_NUM_RAW_PCB                4
#define MEMP_NUM_UDP_PCB                4
#define MEMP_NUM_TCP_PCB                5
#define MEMP_NUM_TCP_PCB_LISTEN         8
#define MEMP_NUM_TCP_SEG                16
#define MEMP_NUM_REASSDATA              5
#define MEMP_NUM_FRAG_PBUF              15
#define MEMP_NUM_ARP_QUEUE              30
#define MEMP_NUM_IGMP_GROUP             8
#define MEMP_NUM_SYS_TIMEOUT            (LWIP_TCP + IP_REASSEMBLY + LWIP_ARP + (2*LWIP_DHCP) + LWIP_AUTOIP + LWIP_IGMP + LWIP_DNS + PPP_SUPPORT)
#define MEMP_NUM_NETBUF                 2
#define MEMP_NUM_NETCONN                4
#define MEMP_NUM_TCPIP_MSG_API          8
#define MEMP_NUM_TCPIP_MSG_INPKT        8
#define MEMP_NUM_SNMP_NODE              50
#define MEMP_NUM_SNMP_ROOTNODE          30
#define MEMP_NUM_SNMP_VARBIND           2
#define MEMP_NUM_SNMP_VALUE             3
#define MEMP_NUM_NETDB                  1
#define MEMP_NUM_LOCALHOSTLIST          1
#define MEMP_NUM_PPPOE_INTERFACES       1
#define PBUF_POOL_SIZE                  16
#define LWIP_ARP                        1
#define ARP_TABLE_SIZE                  10
#define ARP_QUEUEING                    0
#define ETHARP_TRUST_IP_MAC             0
#define ETHARP_SUPPORT_VLAN             0
#define LWIP_ETHERNET                   (LWIP_ARP || PPPOE_SUPPORT)
#define ETH_PAD_SIZE                    0
#define ETHARP_SUPPORT_STATIC_ENTRIES   0
#define IP_FORWARD                      0
#define IP_OPTIONS_ALLOWED              1
#define IP_REASSEMBLY                   1
#define IP_FRAG                         1
#define IP_REASS_MAXAGE                 3
#define IP_REASS_MAX_PBUFS              10
#define IP_FRAG_USES_STATIC_BUF         0
#if IP_FRAG_USES_STATIC_BUF && !defined(IP_FRAG_MAX_MTU)
#define IP_FRAG_MAX_MTU                 1500
#endif
#define IP_DEFAULT_TTL                  255
#define IP_SOF_BROADCAST                0
#define IP_SOF_BROADCAST_RECV           0
#define IP_FORWARD_ALLOW_TX_ON_RX_NETIF 0
#define LWIP_RANDOMIZE_INITIAL_LOCAL_PORTS 0
#define LWIP_ICMP                       1
#define ICMP_TTL                       (IP_DEFAULT_TTL)
#define LWIP_BROADCAST_PING             0
#define LWIP_MULTICAST_PING             0
#define LWIP_RAW                        1
#define RAW_TTL                        (IP_DEFAULT_TTL)
#define LWIP_DHCP                       0
#define DHCP_DOES_ARP_CHECK             ((LWIP_DHCP) && (LWIP_ARP))
#define LWIP_AUTOIP                     0
#define LWIP_DHCP_AUTOIP_COOP           0
#define LWIP_DHCP_AUTOIP_COOP_TRIES     9
#define LWIP_SNMP                       0
#define SNMP_CONCURRENT_REQUESTS        1
#define SNMP_TRAP_DESTINATIONS          1
#define SNMP_PRIVATE_MIB                0
#define SNMP_SAFE_REQUESTS              1
#define SNMP_MAX_OCTET_STRING_LEN       127
#define SNMP_MAX_TREE_DEPTH             15
#define SNMP_MAX_VALUE_SIZE             LWIP_MAX((SNMP_MAX_OCTET_STRING_LEN)+1, sizeof(s32_t)*(SNMP_MAX_TREE_DEPTH))
#define LWIP_IGMP                       0
#define LWIP_DNS                        0
#define DNS_TABLE_SIZE                  4
#define DNS_MAX_NAME_LENGTH             256
#define DNS_MAX_SERVERS                 2
#define DNS_DOES_NAME_CHECK             1
#define DNS_MSG_SIZE                    512
#define DNS_LOCAL_HOSTLIST              0
#define DNS_LOCAL_HOSTLIST_IS_DYNAMIC   0
#define LWIP_UDP                        1
#define LWIP_UDPLITE                    0
#define UDP_TTL                         (IP_DEFAULT_TTL)
#define LWIP_NETBUF_RECVINFO            0
#define LWIP_TCP                        1
#define TCP_TTL                         (IP_DEFAULT_TTL)
#define TCP_WND                         (4 * TCP_MSS)
#define TCP_MAXRTX                      12
#define TCP_SYNMAXRTX                   6
#define TCP_QUEUE_OOSEQ                 (LWIP_TCP)
#define TCP_MSS                         536
#define TCP_CALCULATE_EFF_SEND_MSS      1
#define TCP_SND_BUF                     (2 * TCP_MSS)
#define TCP_SND_QUEUELEN                ((4 * (TCP_SND_BUF) + (TCP_MSS - 1))/(TCP_MSS))
#define TCP_SNDLOWAT                    LWIP_MIN(LWIP_MAX(((TCP_SND_BUF)/2), (2 * TCP_MSS) + 1), (TCP_SND_BUF) - 1)
#define TCP_SNDQUEUELOWAT               LWIP_MAX(((TCP_SND_QUEUELEN)/2), 5)
#define TCP_OOSEQ_MAX_BYTES             0
#define TCP_OOSEQ_MAX_PBUFS             0
#define TCP_LISTEN_BACKLOG              0
#define TCP_DEFAULT_LISTEN_BACKLOG      0xff
#define TCP_OVERSIZE                    TCP_MSS
#define LWIP_TCP_TIMESTAMPS             0
#define TCP_WND_UPDATE_THRESHOLD   (TCP_WND / 4)
#if !defined(LWIP_EVENT_API) && !defined(LWIP_CALLBACK_API)
#define LWIP_EVENT_API                  0
#define LWIP_CALLBACK_API               1
#endif
#define PBUF_LINK_HLEN                  (14 + ETH_PAD_SIZE)
#define PBUF_POOL_BUFSIZE               LWIP_MEM_ALIGN_SIZE(TCP_MSS+40+PBUF_LINK_HLEN)
#define LWIP_NETIF_HOSTNAME             0
#define LWIP_NETIF_API                  0
#define LWIP_NETIF_STATUS_CALLBACK      0
#define LWIP_NETIF_LINK_CALLBACK        0
#define LWIP_NETIF_REMOVE_CALLBACK      0
#define LWIP_NETIF_HWADDRHINT           0
#define LWIP_NETIF_LOOPBACK             0
#define LWIP_LOOPBACK_MAX_PBUFS         0
#define LWIP_NETIF_LOOPBACK_MULTITHREADING    (!NO_SYS)
#define LWIP_NETIF_TX_SINGLE_PBUF             0
#define LWIP_HAVE_LOOPIF                0
#define LWIP_HAVE_SLIPIF                0
#define TCPIP_THREAD_NAME              "tcpip_thread"
#define TCPIP_THREAD_STACKSIZE          1024
#define TCPIP_THREAD_PRIO               (LOWPRIO + 1)
#define TCPIP_MBOX_SIZE                 MEMP_NUM_PBUF
#define SLIPIF_THREAD_NAME             "slipif_loop"
#define SLIPIF_THREAD_STACKSIZE         1024
#define SLIPIF_THREAD_PRIO              (LOWPRIO + 1)
#define PPP_THREAD_NAME                "pppInputThread"
#define PPP_THREAD_STACKSIZE            1024
#define PPP_THREAD_PRIO                 (LOWPRIO + 1)
#define DEFAULT_THREAD_NAME            "lwIP"
#define DEFAULT_THREAD_STACKSIZE        1024
#define DEFAULT_THREAD_PRIO             (LOWPRIO + 1)
#define DEFAULT_RAW_RECVMBOX_SIZE       4
#define DEFAULT_UDP_RECVMBOX_SIZE       4
#define DEFAULT_TCP_RECVMBOX_SIZE       40
#define DEFAULT_ACCEPTMBOX_SIZE         4
#define LWIP_TCPIP_CORE_LOCKING         0
#define LWIP_TCPIP_CORE_LOCKING_INPUT   0
#define LWIP_NETCONN                    1
#define LWIP_TCPIP_TIMEOUT              1
#define LWIP_SOCKET                     1
#define LWIP_COMPAT_SOCKETS             1
#define LWIP_POSIX_SOCKETS_IO_NAMES     1
#define LWIP_TCP_KEEPALIVE              0
#define LWIP_SO_SNDTIMEO                0
#define LWIP_SO_RCVTIMEO                1
#define LWIP_SO_RCVBUF                  0
#define RECV_BUFSIZE_DEFAULT            INT_MAX
#define SO_REUSE                        0
#define SO_REUSE_RXTOALL                0
#define LWIP_STATS                      1
#if LWIP_STATS
#define LWIP_STATS_DISPLAY              0
#define LINK_STATS                      1
#define ETHARP_STATS                    (LWIP_ARP)
#define IP_STATS                        1
#define IPFRAG_STATS                    (IP_REASSEMBLY || IP_FRAG)
#define ICMP_STATS                      1
#define IGMP_STATS                      (LWIP_IGMP)
#define UDP_STATS                       (LWIP_UDP)
#define TCP_STATS                       (LWIP_TCP)
#define MEM_STATS                       ((MEM_LIBC_MALLOC == 0) && (MEM_USE_POOLS == 0))
#define MEMP_STATS                      (MEMP_MEM_MALLOC == 0)
#define SYS_STATS                       (NO_SYS == 0)
#else
#define LINK_STATS                      0
#define IP_STATS                        0
#define IPFRAG_STATS                    0
#define ICMP_STATS                      0
#define IGMP_STATS                      0
#define UDP_STATS                       0
#define TCP_STATS                       0
#define MEM_STATS                       0
#define MEMP_STATS                      0
#define SYS_STATS                       0
#define LWIP_STATS_DISPLAY              0
#endif
#define PPP_SUPPORT                     0
#define PPPOE_SUPPORT                   0
#define PPPOS_SUPPORT                   PPP_SUPPORT
#if PPP_SUPPORT
#define NUM_PPP                         1
#define PAP_SUPPORT                     0
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

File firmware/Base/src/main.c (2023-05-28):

#include <common.h>
#include <test.h>


static void testsRoutines(void)
{
    #if(MAIN_PROGRAM   == PROGRAM_TEST_ENCODER_BASE_ALL)
        test_encoder_base_all();
    #elif(MAIN_PROGRAM == PROGRAM_TEST_ENCODER_BASE_1)
        test_encoder_base(ENCODER_1);
    #elif(MAIN_PROGRAM == PROGRAM_TEST_ENCODER_BASE_2)
        test_encoder_base(ENCODER_2);
    #elif(MAIN_PROGRAM == PROGRAM_TEST_ENCODER_BASE_3)
        test_encoder_base(ENCODER_3);
    #elif(MAIN_PROGRAM == PROGRAM_TEST_ODOMETRY_BASE_ENC_1)
        testOdometryBase(ENCODER_1);
    #elif(MAIN_PROGRAM == PROGRAM_TEST_ODOMETRY_BASE_ENC_1)
        testOdometryBase(ENCODER_1);
    #elif(MAIN_PROGRAM == PROGRAM_TEST_ODOMETRY_BASE_ENC_2)
       testOdometryBase(ENCODER_2);
    #elif(MAIN_PROGRAM == PROGRAM_TEST_ODOMETRY_BASE_ENC_3)
       testOdometryBase(ENCODER_3);
    #elif(MAIN_PROGRAM == PROGRAM_TEST_ODOMETRY_BASE_ALL)
       testOdometryBaseAll();
    #elif(MAIN_PROGRAM == PROGRAM_TEST_MOTOR_1)
       testlldMotor(MOTOR_1);
    #elif(MAIN_PROGRAM == PROGRAM_TEST_MOTOR_2)
       testlldMotor(MOTOR_2);
    #elif(MAIN_PROGRAM == PROGRAM_TEST_MOTOR_3)
       testlldMotor(MOTOR_3);
    #elif(MAIN_PROGRAM == PROGRAM_TEST_MOTOR_ALL)
       testlldMotorAll();
    #elif(MAIN_PROGRAM == PROGRAM_TEST_MOTOR_PER_1)
       testlldMotorPer(MOTOR_1);
    #elif(MAIN_PROGRAM == PROGRAM_TEST_MOTOR_PER_2)
       testlldMotorPer(MOTOR_2);
    #elif(MAIN_PROGRAM == PROGRAM_TEST_MOTOR_PER_3)
       testlldMotorPer(MOTOR_3);
    #elif(MAIN_PROGRAM == PROGRAM_TEST_MOTOR_PER_ALL)
       testlldMotorPerAll();
    #elif(MAIN_PROGRAM == PROGRAM_TEST_SPEED_FILTER_GRAPHS)
        test_speed_filter_graphs();
    #elif(MAIN_PROGRAM == PROGRAM_TEST_CLOSED_SYSTEM_DRIVE)
        testPISpeedMotor();
    #elif(MAIN_PROGRAM == PROGRAM_TEST_I2C)
        testI2C();
    #elif(MAIN_PROGRAM == PROGRAM_TEST_GYROSCOPE)
        testGyroscope();
    #elif(MAIN_PROGRAM == PROGRAM_TEST_KINEMATICS)
        testKinematicsBase();
    #elif(MAIN_PROGRAM == PROGRAM_TEST_JOYSTICK)
        testJoystick();
    #endif
}

int main(void)
{
    halInit();
    chSysInit();
    #if(MAIN_PROGRAM != PROGRAM_MASTER)
        testsRoutines();
    #endif
}

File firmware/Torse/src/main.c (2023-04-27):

#include <common.h>
#include <test.h>
#include "serial.h"

static void testsRoutines(void)
{
    #if(MAIN_PROGRAM == PROGRAM_TEST_SERVO_LEFT_HAND)
        test_lld_servo(LEFT_HAND);
    #elif(MAIN_PROGRAM == PROGRAM_TEST_SERVO_LEFT_WRIST)
        test_lld_servo(LEFT_WRIST);
    #elif(MAIN_PROGRAM == PROGRAM_TEST_SERVO_RIGHT_HAND)
        test_lld_servo(RIGHT_HAND);
    #elif(MAIN_PROGRAM == PROGRAM_TEST_SERVO_RIGHT_WRIST)
       test_lld_servo(RIGHT_WRIST);
    #elif(MAIN_PROGRAM == PROGRAM_TEST_SERVO_NONLINEAR)
       test_lld_nonlinear(LEFT_WRIST);
    #elif(MAIN_PROGRAM==PROGRAM_TEST_ARM_HIGH_FUNCTION)
      test_arm_high_function();
    #elif(MAIN_PROGRAM==PROGRAM_TEST_ARM_CONTROL_SYSTEM)
      test_arm_control_system();
    #elif(MAIN_PROGRAM==PROGRAM_TEST_ARM_KINEMATIC)
      test_arm_kinematic();
    #elif(MAIN_PROGRAM==PROGRAM_TEST_ARM_ENCODER)
        test_arm_encoder();
    #elif(MAIN_PROGRAM==PROGRAM_TEST_PID)
      test_PID();
    #endif
}

int main(void)
{
  halInit();
  chSysInit();

  init_low_level();

  #if(MAIN_PROGRAM != PROGRAM_MASTER)
    testsRoutines();
  #endif
    while (true) {
        chThdSleepMilliseconds(1000);
        palToggleLine(LINE_LED3);
    }
}

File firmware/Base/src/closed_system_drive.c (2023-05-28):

#include "closed_system_drive.h"
#include "serial.h"

#define COEF_SPEED (float)20
#define MAX_SPEED  (float)5
#define MIN_SPEED  (float)(-5)

uint8_t driveInit         = 0;

RegulatorValueMotor regulatorMotor1;
RegulatorValueMotor regulatorMotor2;
RegulatorValueMotor regulatorMotor3;

PIregulator motorForward = {
    .kp              = 0.3,
    .ki              = 0.1,
    .integSaturation = 80 / COEF_SPEED,
    .pDeadZone       = 0,
};

PIregulator motorRevs = {
    .kp              = 0.3,
    .ki              = 0.1,
    .integSaturation = 80 / COEF_SPEED,
    .pDeadZone       = 0,
};

static THD_WORKING_AREA(regulator, 256);
static THD_FUNCTION(CalculationReg, arg){
    arg = arg;
    systime_t time = chVTGetSystemTimeX();
    while (1)
    {
        regulatorMotor1.realSpeed = odometryGetWheelSpeed(REVS_PER_SEC, ENCODER_1);
        regulatorMotor1.pErrSpeed = regulatorMotor1.refSpeed - regulatorMotor1.realSpeed;

        if (regulatorMotor1.refSpeed < 0)
        {
            regulatorMotor1.intgSpeed         += regulatorMotor1.pErrSpeed * motorRevs.ki;
            regulatorMotor1.intgSpeed          = CLIP_VALUE(regulatorMotor1.intgSpeed,
                                                            -motorForward.integSaturation, motorForward.integSaturation);
            regulatorMotor1.speedControlValue  = (motorRevs.kp * regulatorMotor1.pErrSpeed + regulatorMotor1.intgSpeed) * COEF_SPEED;
        }
        else if (regulatorMotor1.refSpeed > 0)
        {
            regulatorMotor1.intgSpeed         += regulatorMotor1.pErrSpeed * motorForward.ki;
            regulatorMotor1.intgSpeed          = CLIP_VALUE(regulatorMotor1.intgSpeed,
                                                            -motorRevs.integSaturation, motorRevs.integSaturation);
            regulatorMotor1.speedControlValue  = (motorForward.kp * regulatorMotor1.pErrSpeed + regulatorMotor1.intgSpeed) * COEF_SPEED;
        }
        else if (regulatorMotor1.refSpeed == 0)
        {
            if (fabsf(regulatorMotor1.refSpeed - regulatorMotor1.realSpeed) > 5)
            {
                if (regulatorMotor1.realSpeed > 0)
                {
                    regulatorMotor1.intgSpeed         += regulatorMotor1.pErrSpeed * motorRevs.ki;
                    regulatorMotor1.intgSpeed          = CLIP_VALUE(regulatorMotor1.intgSpeed,
                                                                    -motorRevs.integSaturation, motorRevs.integSaturation);
                    regulatorMotor1.speedControlValue  = (motorRevs.kp * regulatorMotor1.pErrSpeed + regulatorMotor1.intgSpeed) * COEF_SPEED;
                }
                else
                {
                    regulatorMotor1.intgSpeed         += regulatorMotor1.pErrSpeed * motorForward.ki;
                    regulatorMotor1.intgSpeed          = CLIP_VALUE(
                        regulatorMotor1.intgSpeed, -motorForward.integSaturation, motorForward.integSaturation);
                    regulatorMotor1.speedControlValue  = (motorForward.kp * regulatorMotor1.pErrSpeed + regulatorMotor1.intgSpeed) * COEF_SPEED;
                }
            }
            else
            {
                ResetSpeedRegulatorWheel1();
                regulatorMotor1.speedControlValue = 0;
            }
        }

        regulatorMotor2.realSpeed = odometryGetWheelSpeed(REVS_PER_SEC, ENCODER_2);
        regulatorMotor2.pErrSpeed = regulatorMotor2.refSpeed - regulatorMotor2.realSpeed;

        if (regulatorMotor2.refSpeed < 0)
        {
            regulatorMotor2.intgSpeed         += regulatorMotor2.pErrSpeed * motorRevs.ki;
            regulatorMotor2.intgSpeed          = CLIP_VALUE(regulatorMotor2.intgSpeed,
                                                            -motorRevs.integSaturation, motorRevs.integSaturation);
            regulatorMotor2.speedControlValue  = (motorRevs.kp * regulatorMotor2.pErrSpeed + regulatorMotor2.intgSpeed) * COEF_SPEED;
        }
        else if (regulatorMotor2.refSpeed > 0)
        {
            regulatorMotor2.intgSpeed         += regulatorMotor2.pErrSpeed * motorForward.ki;
            regulatorMotor2.intgSpeed          = CLIP_VALUE(regulatorMotor2.intgSpeed,
                                                            -motorForward.integSaturation, motorForward.integSaturation);
            regulatorMotor2.speedControlValue  = (motorForward.kp * regulatorMotor2.pErrSpeed + regulatorMotor2.intgSpeed) * COEF_SPEED;
        }
        else if (regulatorMotor2.refSpeed == 0)
        {
            if (fabsf(regulatorMotor2.refSpeed - regulatorMotor2.realSpeed) > 5)
            {
                if (regulatorMotor2.realSpeed > 0)
                {
                    regulatorMotor2.intgSpeed         += regulatorMotor2.pErrSpeed * motorRevs.ki;
                    regulatorMotor2.intgSpeed          = CLIP_VALUE(regulatorMotor2.intgSpeed,
                                                                    -motorRevs.integSaturation, motorRevs.integSaturation);
                    regulatorMotor2.speedControlValue  = (motorRevs.kp * regulatorMotor2.pErrSpeed + regulatorMotor2.intgSpeed) * COEF_SPEED;
                }
                else
                {
                    regulatorMotor2.intgSpeed         += regulatorMotor2.pErrSpeed * motorForward.ki;
                    regulatorMotor2.intgSpeed          = CLIP_VALUE(
                        regulatorMotor2.intgSpeed, -motorForward.integSaturation, motorForward.integSaturation);
                    regulatorMotor2.speedControlValue  = (motorForward.kp * regulatorMotor2.pErrSpeed + regulatorMotor2.intgSpeed)   * COEF_SPEED;
                }
            }
            else
            {
                ResetSpeedRegulatorWheel2();
                regulatorMotor2.speedControlValue = 0;
            }
        }
        regulatorMotor3.realSpeed = odometryGetWheelSpeed(REVS_PER_SEC, ENCODER_3);
        regulatorMotor3.pErrSpeed = regulatorMotor3.refSpeed - regulatorMotor3.realSpeed;
        if (regulatorMotor3.refSpeed < 0)
        {
            regulatorMotor3.intgSpeed        += regulatorMotor3.pErrSpeed * motorRevs.ki;
            regulatorMotor3.intgSpeed         = CLIP_VALUE(regulatorMotor3.intgSpeed,
                                                           -motorRevs.integSaturation, motorRevs.integSaturation);
            regulatorMotor3.speedControlValue = (motorRevs.kp * regulatorMotor3.pErrSpeed + regulatorMotor3.intgSpeed) * COEF_SPEED;
        }
        else if (regulatorMotor3.refSpeed > 0)
        {
            regulatorMotor3.intgSpeed         += regulatorMotor3.pErrSpeed * motorForward.ki;
            regulatorMotor3.intgSpeed          = CLIP_VALUE(regulatorMotor3.intgSpeed,
                                                            -motorForward.integSaturation, motorForward.integSaturation);
            regulatorMotor3.speedControlValue  = (motorForward.kp * regulatorMotor3.pErrSpeed + regulatorMotor3.intgSpeed) * COEF_SPEED;
        }
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

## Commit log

2021-08-30 DC Motor driver schematics and some info about servo (#17)
2021-08-30 Dc motor driver (#19)
    * DC Motor driver schematics and some info about servo
    * driver schematic important fix
    * driver schematic important fix
2021-09-04 Addition of fuse and small fixes (#20)
2021-09-12 add table driver for DC Motor (#22)
    * add table driver for DC Motor
    * new table
2021-09-18 arm pwm control
2021-09-20 Feature/3 system arch (#26)
    * #3 Block-scheme: added power requirements and connections
    * #3 Exported image of scheme
2021-09-28 Feature base encoder info (#33)
    * update info base encoder
    * update info base encoder
2021-09-29 14 feature encoder (#25)
    * #14_feature_encoder
    * small developments with an encoder
    * small developments with an encoder
    * added decoration
    * added decoration
    * add test folder and comments
    * fix decor
    * fix decode
    * fix decor2
    * fix decor2
    [common.h, encoder.c, halconf.h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]
2021-10-20 24 kinematic measurement (#40)
    * dimensions
    * dimensions file rename
2021-10-22 test version arm close sys
2021-10-30 electrical board for driver dpt (#38)
    * electrical board for driver dpt
    * fixes board
    * add rar
    * add drill
    * zip
    [PCB1.PcbDoc, PCB1_lack.PcbDoc, PCB1_no_lack.PcbDoc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]
2021-11-19 add typedef arm and universal function for hands
2021-11-22 fix pid
2021-12-04 incomplete integration of the second driver
2022-01-19 all structures for setting up the driver are placed in a separate header
2022-01-22 uploaded a non-current version
2022-01-23 pwm problem
2022-01-25 work on the driver is finished, starting to write tests
2022-01-30 add new elbow driver and change close system
2022-02-06 add arm_driver doc and fix after review
    [elbow_driver.c, lld_bb_driver.c, lld_red_driver.c]
2022-02-06 Update arm driver.md
2022-03-04 add lld_bridge_system.h and some fix after review
    [close_sys_arm.c, common.h, elbow_driver.c]
2022-03-18 Final version (#65)
    [platform_encoder_holder.SLDPRT, platform_encoder_holder.STL, sensor_holder_left.STL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]
2022-03-22 29 kinematic model (#62)
    * kinematic initial commit
    * base kinematic
    * new picture
    * test show LaTex
    * test 2
    * test 3
    * Update omniwheel_kinematics.md
    * test 4
    * test 5
    * name
    * name attempt 2
    * table test
    * equations and their derivation
    * equations and their derivation (corrected)
    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
2022-03-28 16 feature close arm sys (#60)
    * test version arm close sys
    * add left hand close system
    * add typedef arm and universal function for hands
    * fix pid
    * add new elbow driver and change close system
    * add comments and test
    * update in accordance with arm_driver
    * update doc and tab
    * add lld_bridge_system.h and some fix after review
    * add some tests and fix after review
    * add tests
    * [#16] Added scheme and some functions protos
    * [#16] Last scheme changes
    * feedback works, test freezes
    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
    [common.h, elbow_driver.c, encoder.c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]
2022-04-08 67 c kinematic (#74)
    * test_and_comment
    * full_comment
    * cleaning
    * solving_problem
    * unit and comment
    * constants side
2022-04-08 73 feature arm encoder (#75)
    * add arm_encoder module
    * fix after tests
    * added some decoration
    * fix after review
    [common.h, elbow_driver.c, encoder.c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]
2022-04-16 [RF]: refactoring, fix - hanging forever text_elbow
    [elbow_driver.c, part_arm_driver.c]
2022-04-28 cs arm
    [st_nucleo_f7.cfg]
2022-07-17 New files + added description (#85)
    [bot_part_shifted.SLDPRT, bot_part_shifted.STL, bot_part_symmetrical.SLDPRT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]
2022-10-07 robo_lib (#91)
    * robo_lib
    * move robo_lib to firmware
    * Delete firmware/Torse/.metadata directory
    [st_nucleo_f7.cfg]
2022-10-20 control lld motors
2022-10-22 78 arm refact (#93)
    * arm refact
    * pid update
2022-10-30 55 code formatter (#87)
    * [RF]: add poetry and formatters
    * [RF]: add info into README
    * [RF]: add info into README
    * Update README.md
    * Added actions workflow
    * Updated to have each linter by itself
    * Fixed cpplint call
    * Fixed cpplint call
    * Updated structure
    [CPPLINT.cfg]
2022-11-20 77 feature arm trajectory (#94)
    * kinematic
    * kinematic
    * rename part_arm_driver, add arms module, todo check kinematic
    * add time macros
    * update info about angle lim + matlab script arm tracing
    * fix after test with matlab model
    * where is my debug mode...
    * correction kinematic after tests
    * misspell
    [common.h, elbow_driver.c, main.c]
2022-11-22 a test version of the calibration, todo check on Thursday
2022-12-04 arm proto gui
2022-12-30 add pin usage
2023-03-18 Transfer files from LFS
    [bot_part_shifted.SLDPRT, bot_part_shifted.STL, bot_part_symmetrical.SLDPRT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]
2023-03-25 correction control system after calibratin
    [common.h, elbow_driver.c]
2023-04-01 [RF]: motor refactoring
2023-04-01 [RF]: odometry_base refactoring
2023-04-08 work version gyro
2023-04-15 fix formuls kinematics
2023-04-18 fix formul kinematics
2023-04-26 add comment kinematics

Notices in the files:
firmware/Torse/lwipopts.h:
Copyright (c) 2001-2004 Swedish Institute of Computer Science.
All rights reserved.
